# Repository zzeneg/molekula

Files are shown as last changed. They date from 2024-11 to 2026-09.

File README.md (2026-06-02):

# molekula: keyboard & framework

## modular framework

This project aims to provide components for building modular ergo keyboards by separating one main PCB into central and side parts. **Side** is a dumb PCB, with key matrix only (up to 25 keys), and accepts all switch types (MX/ChocV1/ChocV2/GLP). **Central** is a keyboard brain, which contains any MCU (wired/wireless/integrated) and additional hardware - encoders/touchpads/trackballs/displays/etc, while keeping its size under 100x100mm. PCBs are interconnected with 12-pin FFC cables, and can be replaced/updated independently.

Such modular approach allows for quick, cheap and easy experimenting with different hardware, prototyping, and reusing of side PCBs.

### PCB examples

- central with pro-micro/nice!nano footprint, nice!view and rotary encoder

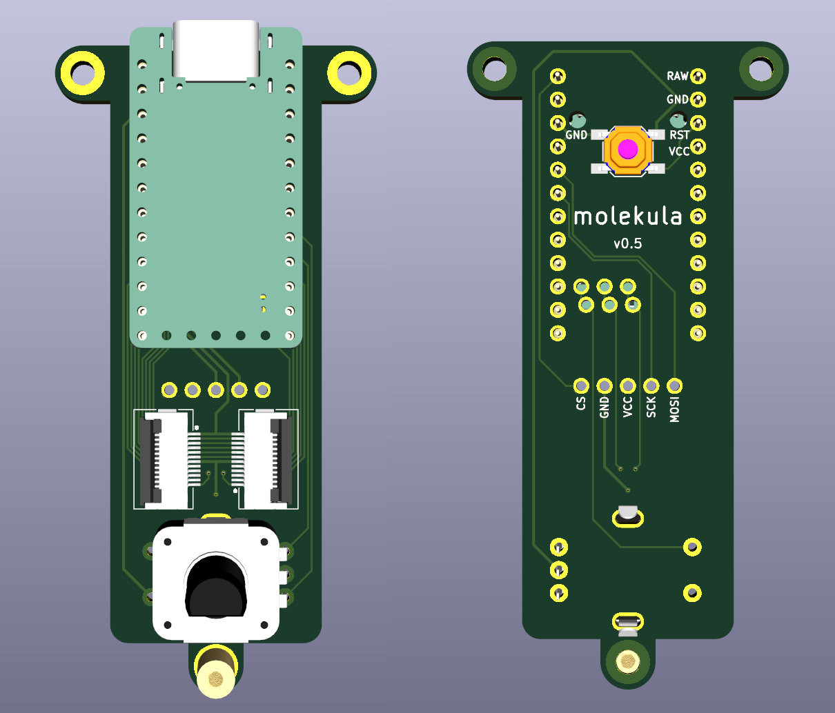
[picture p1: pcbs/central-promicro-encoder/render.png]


- side with 18 keys and minY spacing (19x16mm)

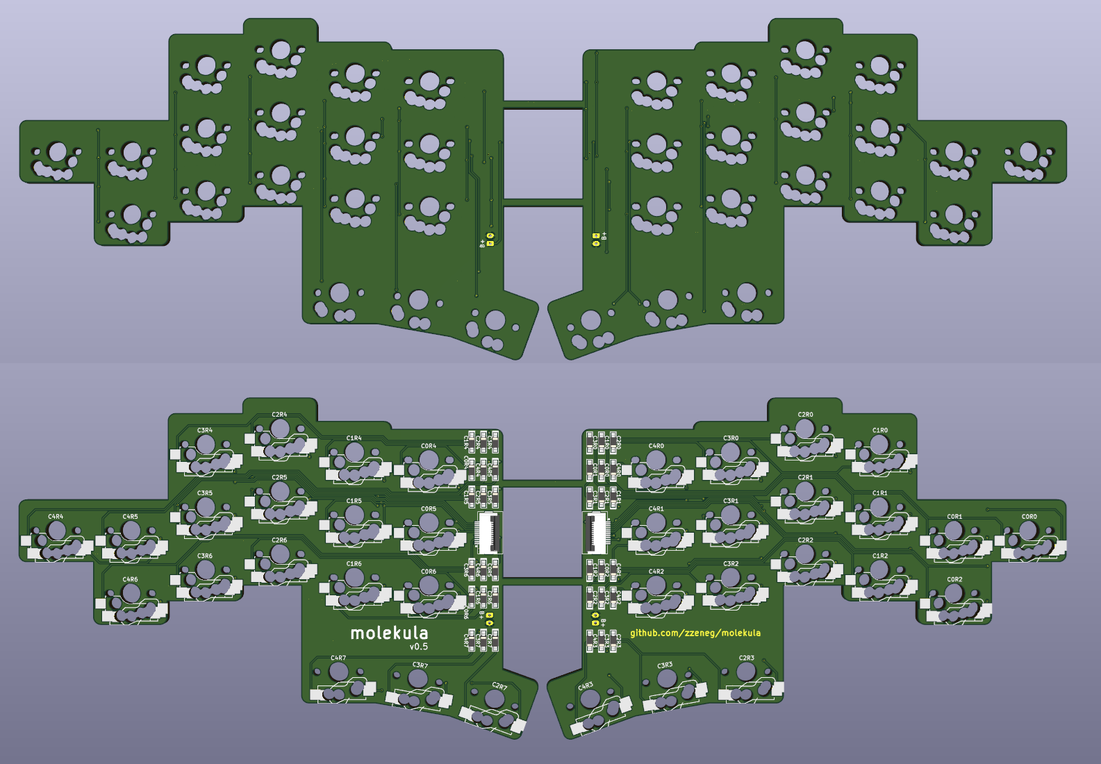
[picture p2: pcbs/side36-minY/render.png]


## Molekula keyboards

Reference design using molekula PCBs.

Features:

- minY (19x16mm) spacing
- 36 keys
- wireless
- nice!view support
- rotary encoder

### Molekula2

Unibody that can be disassembled into two parts for traveling

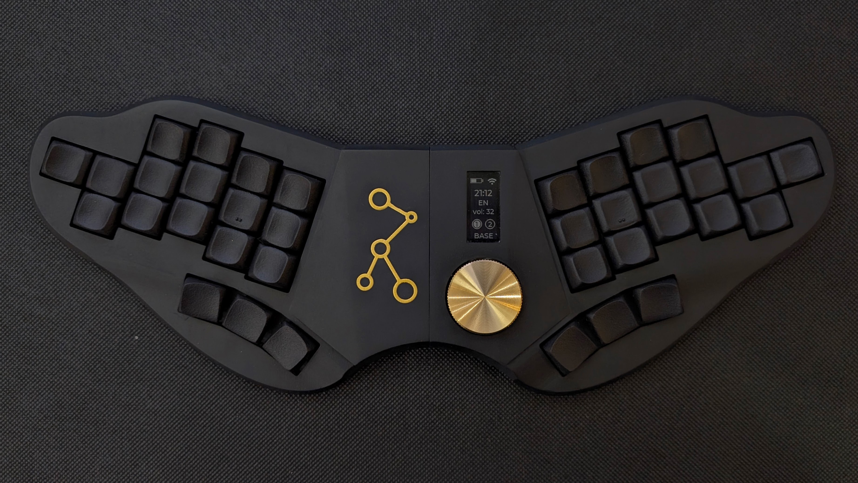
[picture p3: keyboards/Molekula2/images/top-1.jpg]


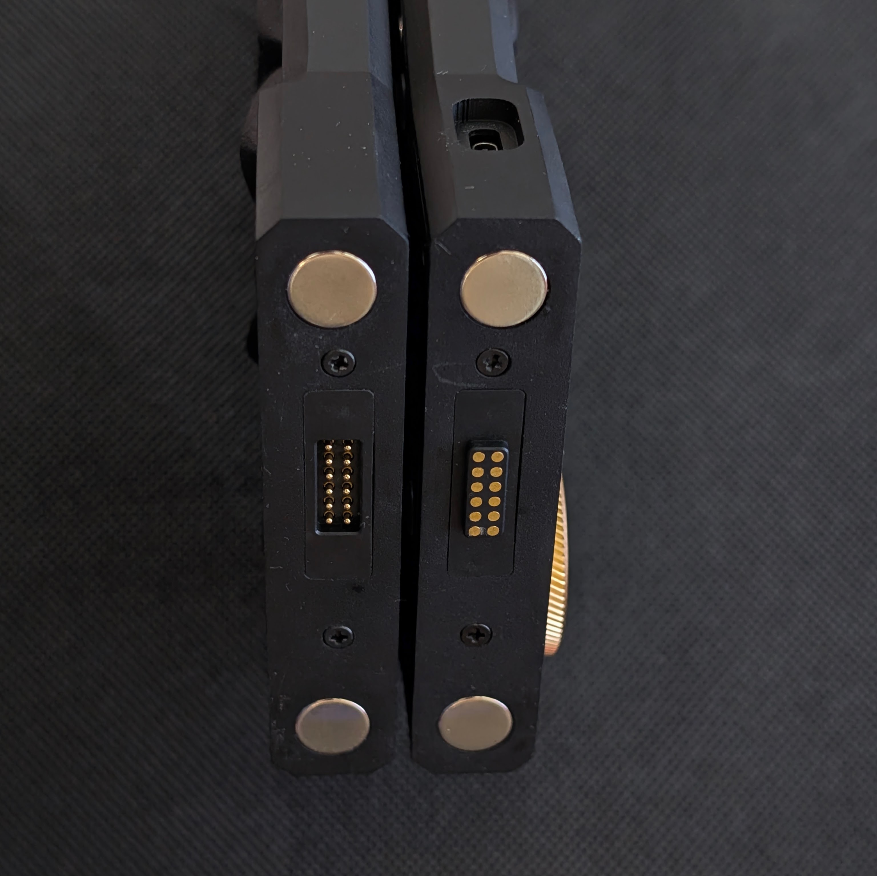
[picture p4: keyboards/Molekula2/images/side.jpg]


[More info and build guide](./keyboards/Molekula2/README.md)

### Molekula3

Unibody assembled from multiple parts, to allow easy modifications and experiments.

- optimised for FDM printing
- configurable angle and distance between sides (default is 18deg and 60mm)
- different options with dongle or nice!view
- MX/KS-33/ChocV1/ChocV2 are supported, except thumbs are low-profile only

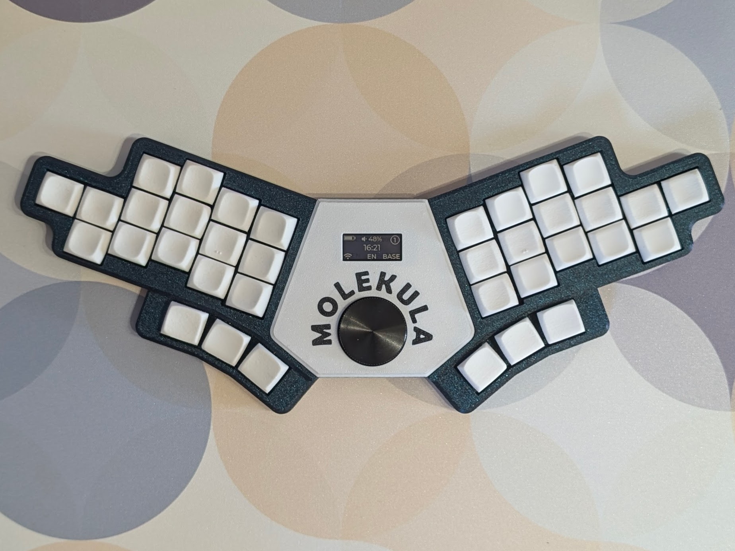
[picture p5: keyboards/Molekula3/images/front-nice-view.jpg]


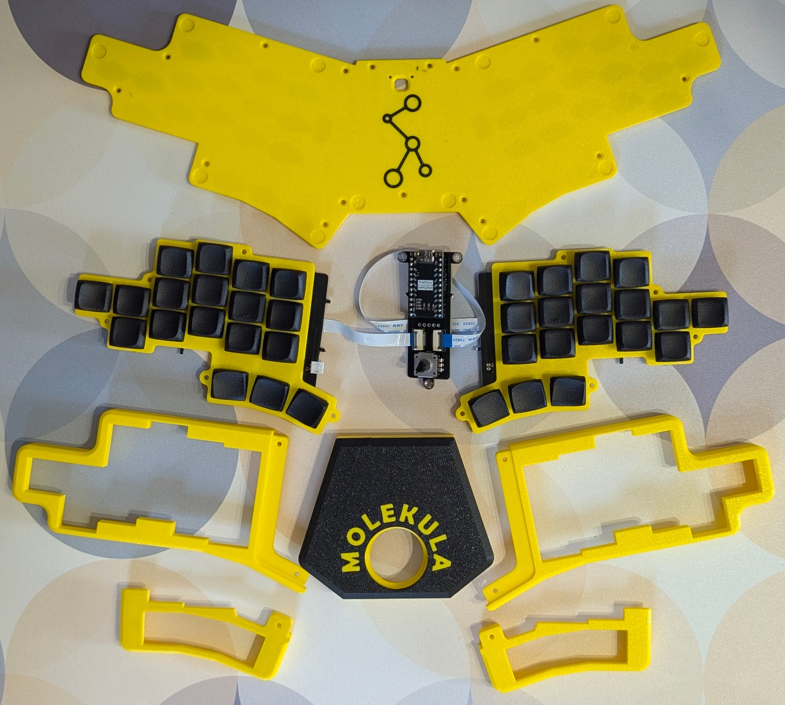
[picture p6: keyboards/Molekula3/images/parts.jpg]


[More info and build guide](./keyboards/Molekula3/README.md)

### minY keycaps

Keycaps designed for minY spacing (19mmx16mm):

- [MX DES](./keycaps/MX-DES-minY/)
- [Choc DES](./keycaps/MX-DES-minY/) - optimised for FDM printing

### Support

If you like my work and want to support my future designs, please consider [sponsorship](https://github.com/sponsors/zzeneg).

### Sponsors

Molekula2 keyboard was sponsored by PCBWay. I can highly recommend their PCBA and 3D printing services - "Imaging Black" resin looks fantastic.





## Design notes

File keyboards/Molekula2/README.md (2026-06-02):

## Molekula2 keyboard

Reference design using molekula framework PCBs.

Features:

- minY (19x16mm) spacing
- unibody that can be disassembled into two parts for traveling
- 36 keys
- wireless
- nice!view support
- rotary encoder



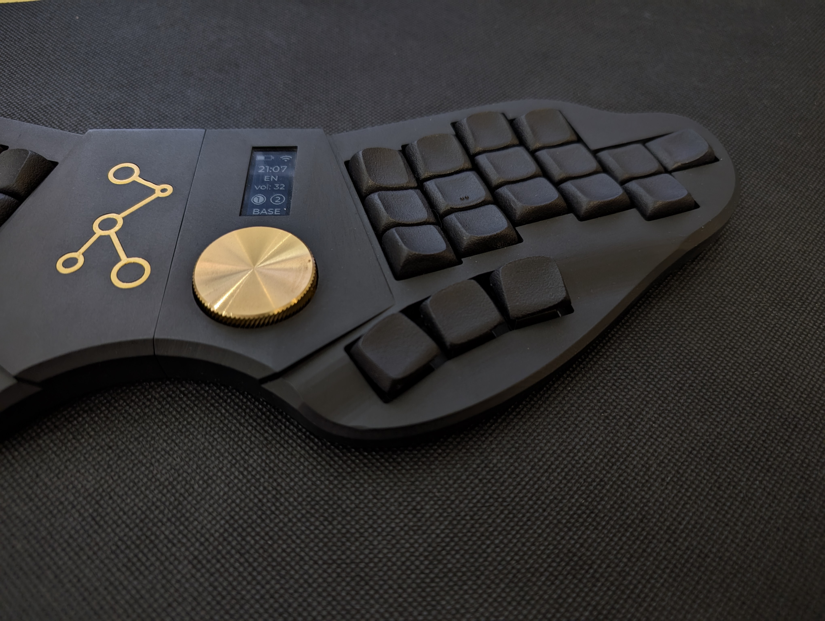
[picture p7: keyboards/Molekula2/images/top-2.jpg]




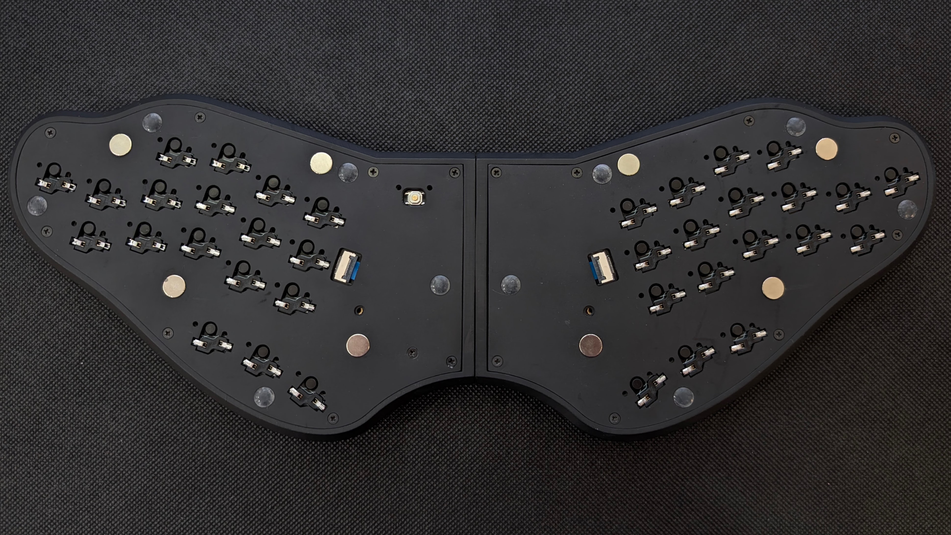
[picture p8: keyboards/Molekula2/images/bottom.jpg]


## Firmware

- [molekula shield](https://github.com/zzeneg/zmk-molekula) with default keymap and ZMK Studio support
- [my custom keymap](https://github.com/zzeneg/zmk-config), can be used as reference if needed

## Bill of materials

- MCU - nice!nano _(recommended to support original creator)_ or its chinese clone
- 36 MX/KS-33/Choc switches
- 36 MX/KS-33/Choc hotswap sockets
- 36 [SMD SOD-123 1N4148](https://www.aliexpress.com/item/1005002882901030.html) diodes
- Battery up to 602040 size - this is what I'm using, should be enough but you may try to go bigger (check that there's enough space inside using 3D project)
- _[Optional]_ Vertical 2pin 2.54mm JST [connector](https://www.aliexpress.com/item/1005004938361514.html) for battery
- [Magnetic connector 12pin](https://www.aliexpress.com/item/1005004609718442.html)
- 1 rotary encoder, [low profile EC12](https://www.aliexpress.com/item/1005003636548797.html) is recommended (no click though). Versions with click often has issues with power consumption, be careful
- 1 [30mm knob](https://www.aliexpress.com/item/1005001783212821.html)
- 4/5mm, 6/8mm and 10mm [M2 screws with flat head](https://www.aliexpress.com/item/4001248931159.html) (choose black or silver based on case color/preference)
- [M2 nuts](https://www.aliexpress.com/item/1005001412230125.html)
- M2 3/4mm [heatset inserts](https://www.aliexpress.com/item/1005004624377733.html) - diameter 3.2mm for resin case or 3.5mm for thermoplastic
- Vertical 12pin 0.5mm [FFC/FPC connector](https://www.aliexpress.com/item/10000000737049.html)
- Horizontal 12pin 0.5mm [FFC/FPC connector](https://www.aliexpress.com/item/10000348360254.html)
- 12pin 0.5mm 5cm [FFC cable](https://www.aliexpress.com/item/1005007561337665.html) - both reverse and same side variants
- SMD 4x4x1.5mm [push button](https://www.aliexpress.com/item/32802382507.html)
- [7x1.5mm legs](https://www.aliexpress.com/item/1005002995402961.html)
- [10x3mm magnets](https://www.aliexpress.com/item/1005006802780901.html) - for connecting sides
- [8x2mm magnets](https://www.aliexpress.com/item/1005005426580014.html) - for transportation (optional)
- 2.54mm female pin [headers](https://www.aliexpress.com/item/4001122376295.html)
- 5pin [headers](https://www.aliexpress.com/item/1005005742644313.html) - source of pins for socketing, and also a connector for nice!view

## PCBA

PCBA is recommended, all PCBs are combined into one, BOM and Position files are tested. If you can manually solder FFC connectors with 0.5mm pitch (it's totally doable), ignore PCBA and order PCBs separately.

## Case

See STLs in [./case]() folder. There are separate top/bottom parts for ChocV1/ChocV2/KS-33/MX switches. Also there is left side with and without logo. Separate logo can be printed in another color and inserted.

## Build guide

### Tools

- Soldering iron. Any iron will work, but I highly recommend something small like TS100 or Pinecil with TS-K tip, it's good for SMD soldering
- Solder wire, preferably with lead if you can get one. For EU I recommend this [shop](https://botland.store) and Cynel brand, 0.56mm and 0.9mm
- [Flux](https://www.aliexpress.com/item/1005004675178847.html)
- Flush cutters - be extra careful when cutting pins, always use eye protection
- Hot glue (for nice!view only), instant glue (for resin case only)
- Tweezers (I prefer [reverse](https://www.aliexpress.com/item/1005004188266714.html) instead of regular), pliers, soldering mat, isopropyl alcohol (IPA) and [cotton pads](https://www.aliexpress.com/item/1005003798227116.html) for cleaning

### Preparations

- download [latest firmware](https://github.com/zzeneg/zmk-molekula/actions), flash it to MCU and pair with your PC. It's easier to do it now and also check that MCU actually works
- read through the whole build guide
- break combined PCB into separate parts with pliers, do not sand break-offs

### Soldering

I used PCBA for final version, so I'll skip over FFC/diode soldering. Check my [duet guide](https://github.com/zzeneg/duet/blob/main/guide/readme.md) if needed.

#### Central

Start with MCU socketing (top side is the one with FFC connectors). Prepare MCU headers - you'll need two strips of 12 pins. Don't try to break the header between the pins, instead count the required number of pins, and break in middle of a next pin. Discard that pin and cut the plastic with flush cutters - it'll look much better. Assemble headers like this (using extra headers for stabilization):

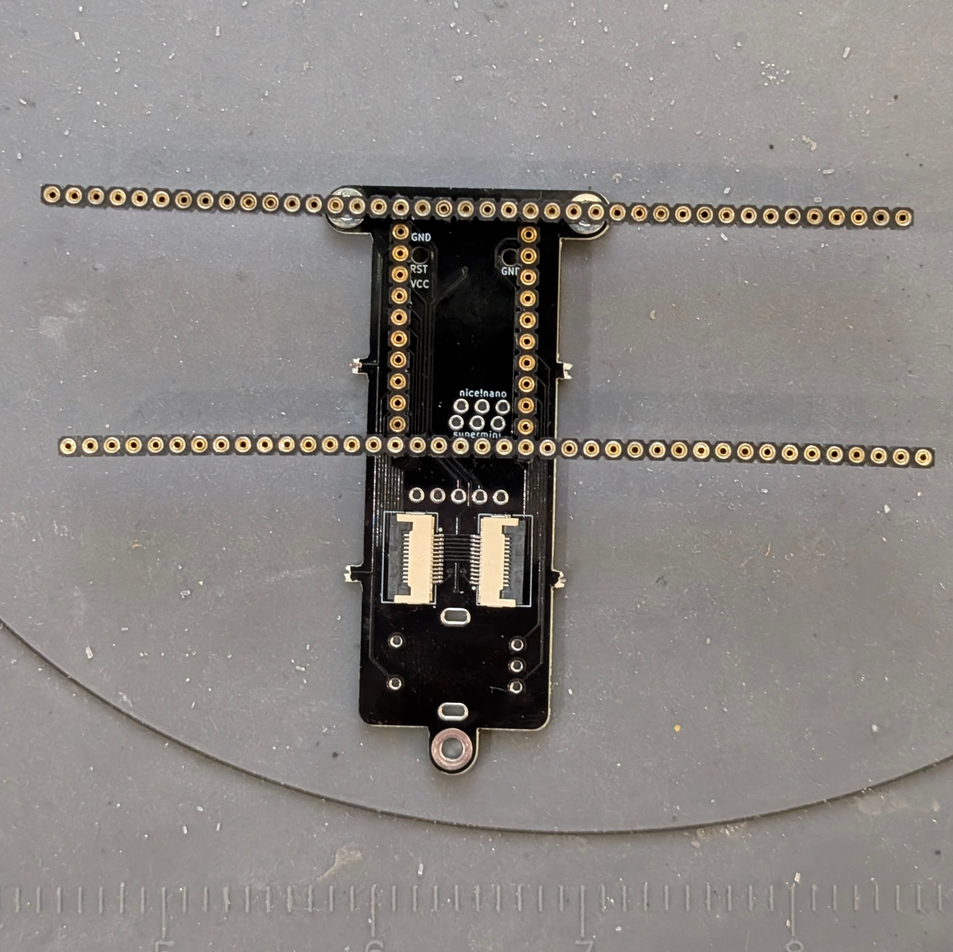
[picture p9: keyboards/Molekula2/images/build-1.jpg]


Flip carefully and solder all pins starting from corners. I prefer to cut first and then solder but you can cut afterwards as well, just remember to do it as bottom case has only 1.2mm space there. Pins in the middle are used only for encoder click, ignore them if you don't use it.

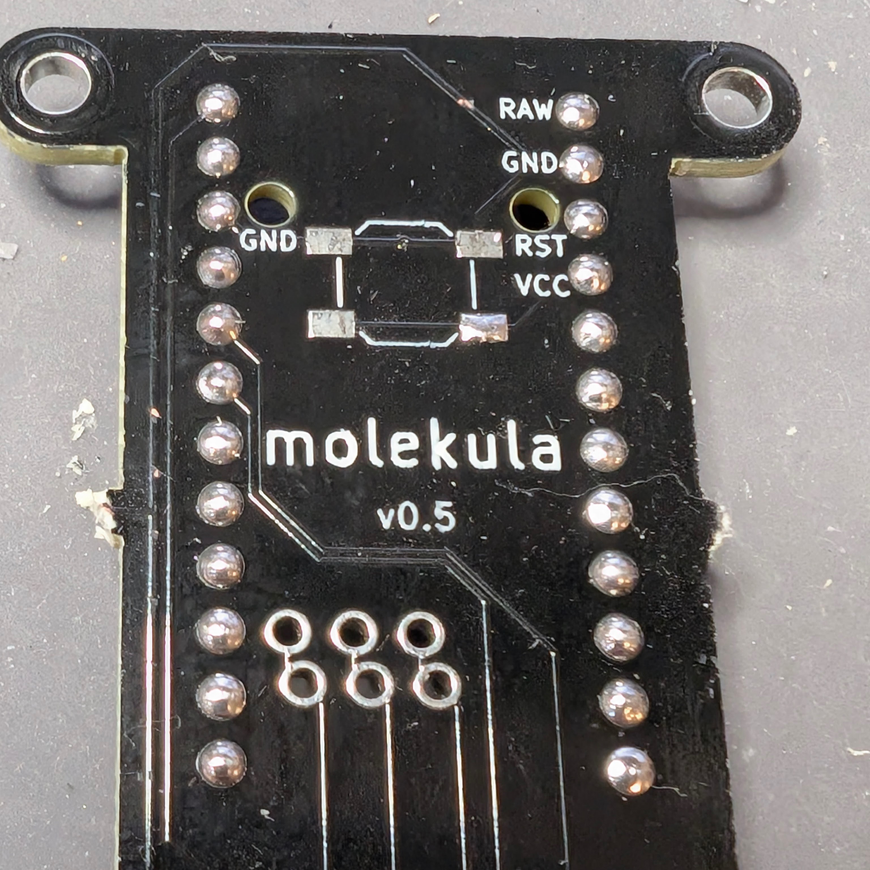
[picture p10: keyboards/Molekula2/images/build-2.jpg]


Pull out 24 pins from RGB headers (I use two pliers for that) and put a piece of masking tape over all headers leaving some space in between for MCU components.

Align MCU holes with headers ignoring top row of holes on the MCU, they are not used/soldered. Insert pins one by one (cut them if you prefer but it's not required). Solder everything starting from corners.

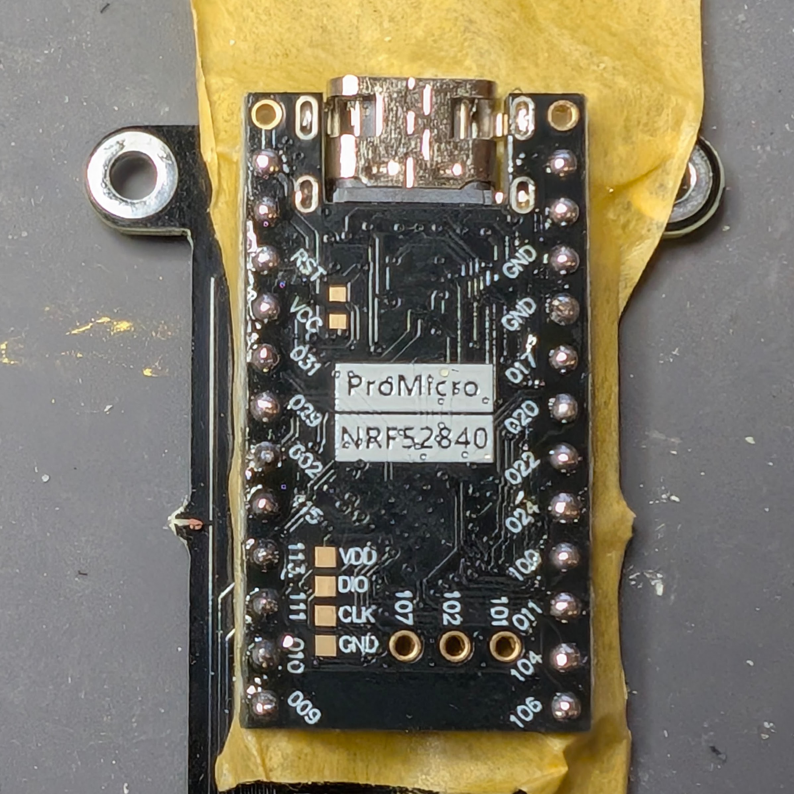
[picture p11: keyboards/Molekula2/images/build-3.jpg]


Carefully pull out socketed MCU and remove tape. Now solder the nice!view header and reset button on the back. Finish central with rotary encoder. Done.

#### Magnetic connectors

Prepare two connector PCB with soldered FFC connectors (if soldering manually, make sure black part is facing the side where the breakoffs are). Put them onto magnetic connectors, the one with a "leg" should be on the left side, and FFC's black part should be facing you.

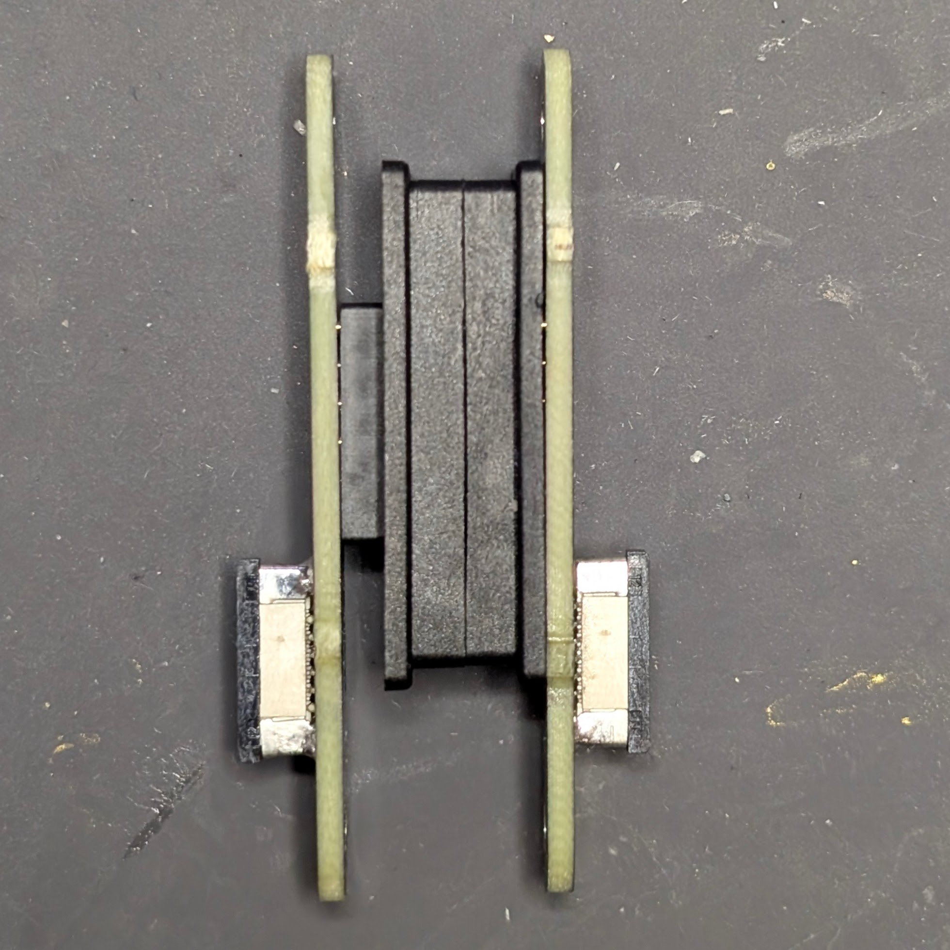
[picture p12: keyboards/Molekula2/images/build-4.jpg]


Take them apart and solder without flipping anything. It's a bit tricky because of magnets but doable with two hands. The easiest approach is to add a lot of flux and drag solder across all contacts.

#### Side PCBs

Just solder the hotswap sockets. They are not symmetrical, look at silkscreen on how to place them. Make sure that socket is fully inserted into the PCB. You have use a lot of solder as there are a lot of holes but try to avoid big solder blobs - they may collide with bottom case.

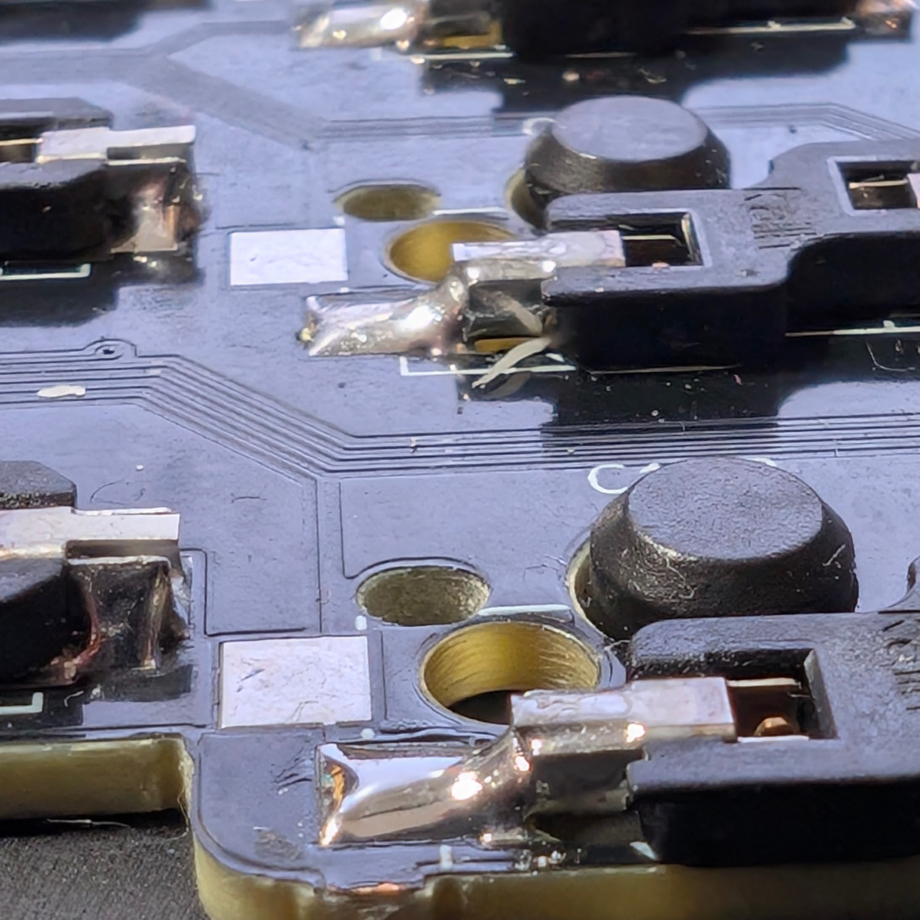
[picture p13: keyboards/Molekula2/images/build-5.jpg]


If you want a JST socket for the battery - solder it to the left PCB (JST should be on the top side). Double check the polarity on the battery connector, and do not connect it yet.

#### nice!view

Take a 5-pin header and carefully move pins, leaving around 1.5mm on one side and solder short side to nice!view.

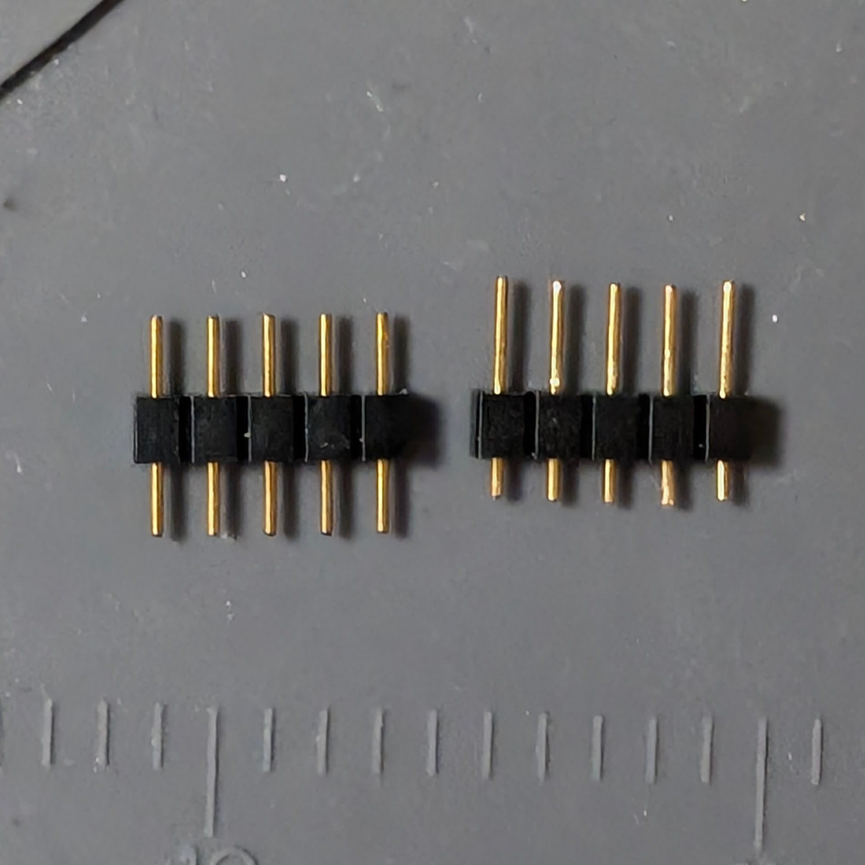
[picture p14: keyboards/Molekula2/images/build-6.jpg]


Attach nice!view to the case with hot glue - add more around the pins.

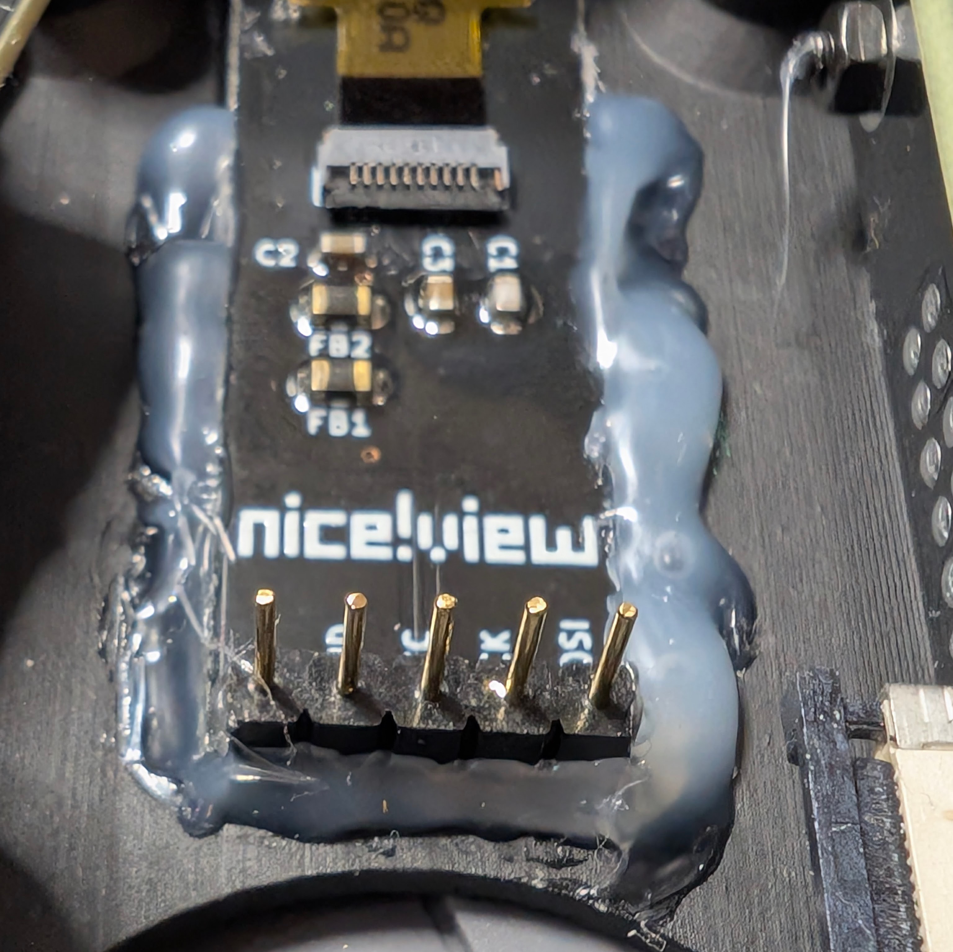
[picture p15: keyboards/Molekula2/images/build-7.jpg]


#### Assembly

First insert socketed MCU and attach all FFC cables outside the case and perform basic checks for shorts between BAT/GND/VCC/B+/B-. If everything is ok, solder your battery to the PCB or connect it with JST.

Put screw inserts into the case. For thermoplastics (MJF, PLA, etc) use 3.5mm-wide and look at [this guide](https://docs.bastardkb.com/bg_charybdis/04screw_inserts.html) for detailed instructions on heat inserts. For resin case take 3.2mm inserts and use instant glue (cyanoacrylate) and/or a drill if the holes are too narrow.

Insert 10mm magnets, they should go all the way in so there is no gap between sides, use more force if needed. If loose, add a bit of instant glue inside.

Assemble left side first - insert magnetic connector into the case (bigger one with a "leg") with already attached FFC cable, fix connector PCB in place with 10mm screws. Hot glue your battery to the case, and connect FFC to side PCB. Insert several switches to hold the PCB in place.

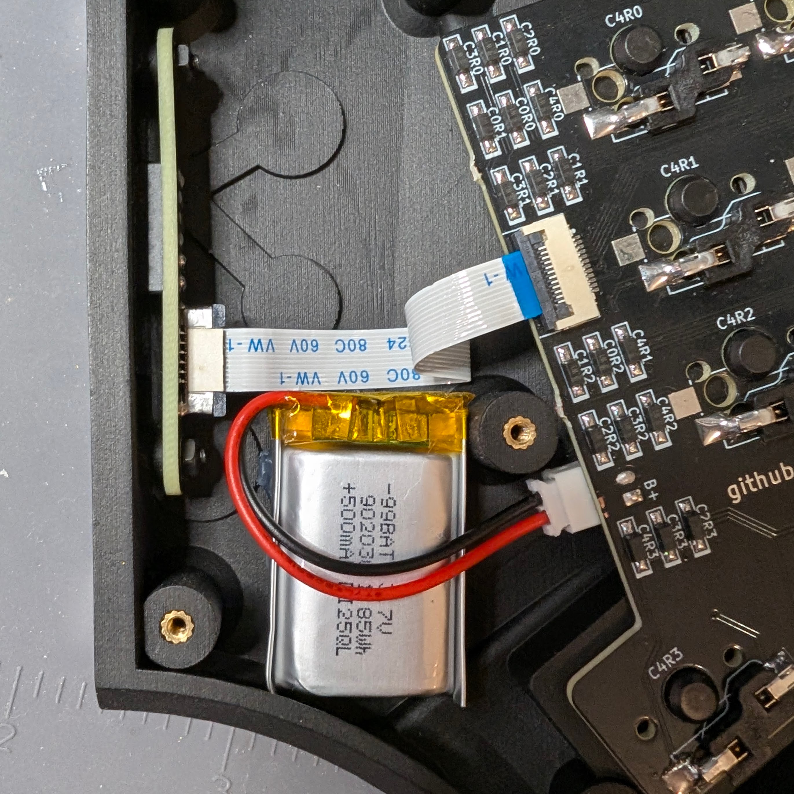
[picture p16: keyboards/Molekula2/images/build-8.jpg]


Now right side - start with magnetic connector, for this side use 6-8mm screws. Connect FFC cables, carefully put central PCB in place, looking at n!v pins. After that, bend and press the FFC cable going to magnetic connector - it should be flat to hide under encoder knob (the other cable has a lot of place).

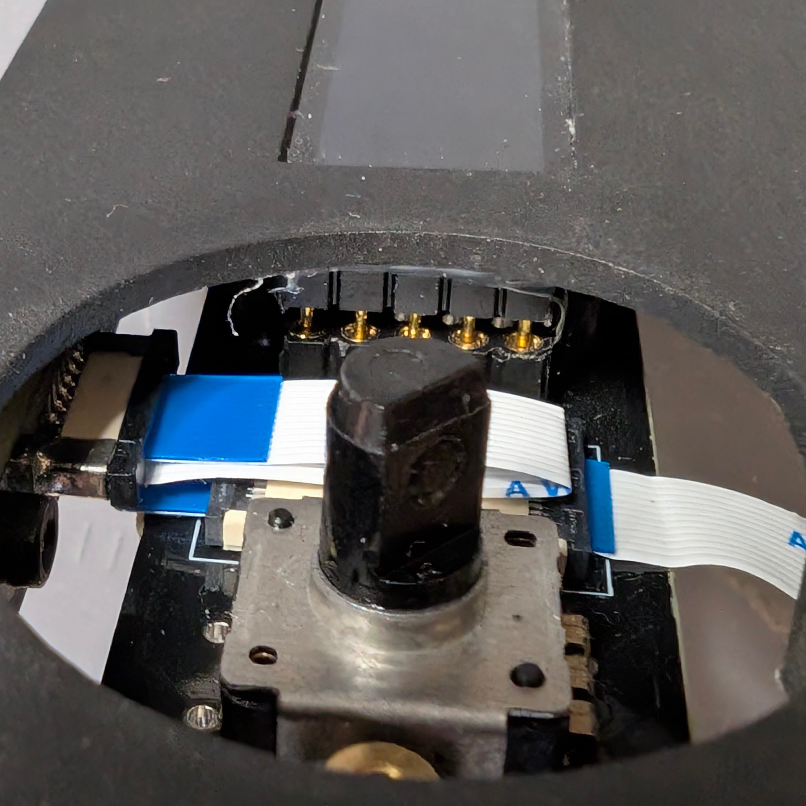
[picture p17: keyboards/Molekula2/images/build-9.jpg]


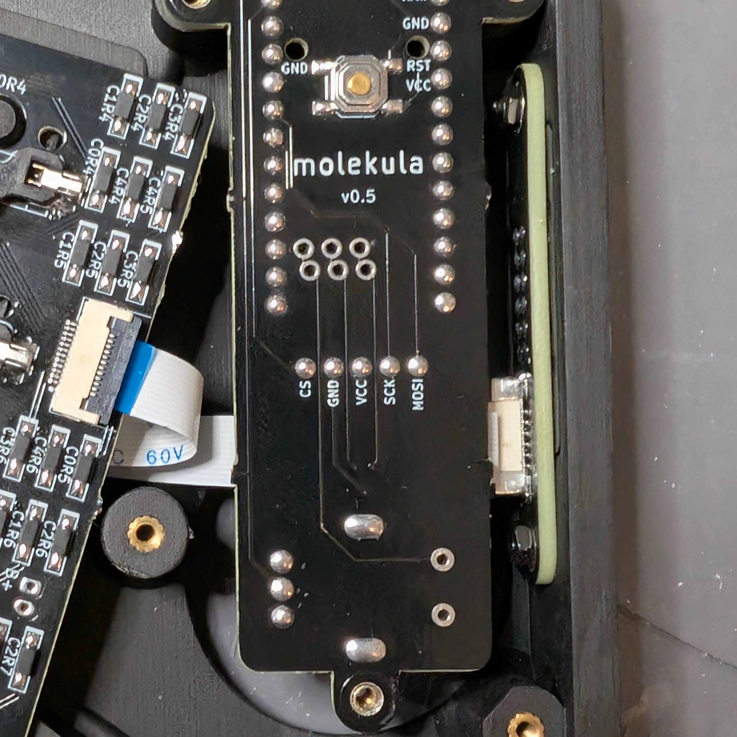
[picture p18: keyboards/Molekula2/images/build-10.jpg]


Now attach encoder knob. I recommend to put it around 2-3mm higher than the lowest position.

Last step is to add bottom plate, use 4-5mm screws for this.

Done!

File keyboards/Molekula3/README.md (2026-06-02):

## Molekula3 keyboard

Unibody assembled from multiple parts, to allow easy modifications and experiments.

- optimised for FDM printing
- configurable angle and distance between sides
- different options with and without nice!view





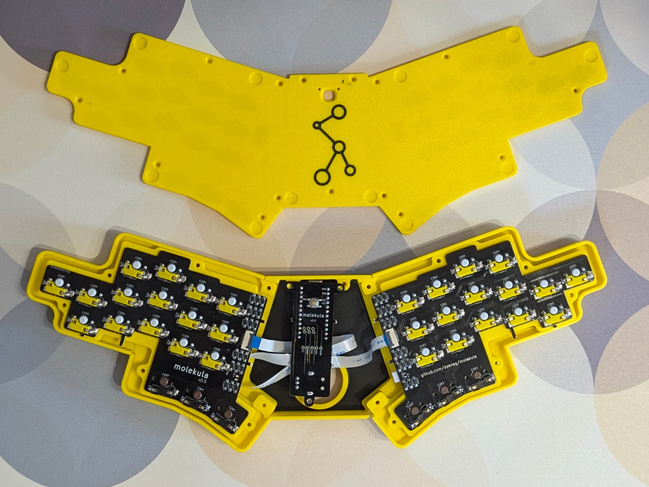
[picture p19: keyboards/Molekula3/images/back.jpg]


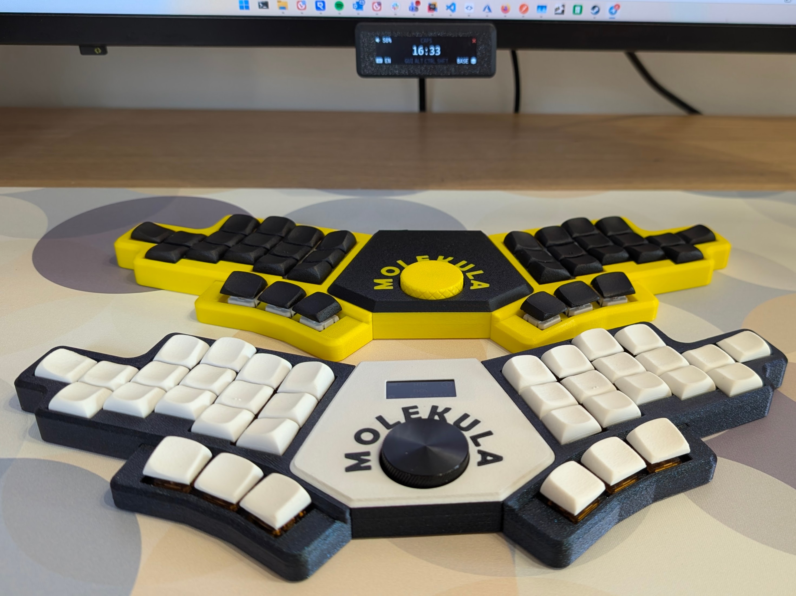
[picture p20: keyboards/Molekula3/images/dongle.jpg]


## Firmware

- [molekula shield](https://github.com/zzeneg/zmk-molekula) with default keymap and ZMK Studio support, with variants for horizontal nice!view and [dongle](https://github.com/zzeneg/underdongle)
- [my custom keymap](https://github.com/zzeneg/zmk-config), can be used as reference if needed

## Bill of materials

- MCU - nice!nano _(recommended to support original creator)_ or its chinese clone
- 36 (30 MX/KS-33/Choc + 6 KS-33/Choc) switches
- 36 (30 MX/KS-33/Choc + 6 KS-33/Choc) hotswap sockets
- 36 [SMD SOD-123 1N4148](https://www.aliexpress.com/item/1005002882901030.html) diodes
- Battery like 902030 size - this is what I'm using, should be enough but you may try to go bigger (check that there's enough space inside using 3D project)
- _[Optional]_ Vertical 2pin 2.54mm JST [connector](https://www.aliexpress.com/item/1005004938361514.html) for battery
- 1 rotary encoder, [low profile EC12](https://www.aliexpress.com/item/1005003636548797.html) is recommended (no click though). Versions with click often has issues with power consumption, be careful
- 1 [30mm knob](https://www.aliexpress.com/item/1005001783212821.html) - or 3D printed one
- 8mm and 14mm [M2 screws with flat head](https://www.aliexpress.com/item/4001248931159.html) (choose black or silver based on case color/preference)
- [M2 nuts](https://www.aliexpress.com/item/1005001412230125.html)
- M2 2mm and 4mm [heatset inserts](https://www.aliexpress.com/item/1005004624377733.html) - diameter 3.2mm for resin case or 3.5mm for thermoplastic
- Horizontal 12pin 0.5mm [FFC/FPC connector](https://www.aliexpress.com/item/10000348360254.html)
- 12pin 0.5mm 5cm [FFC cable](https://www.aliexpress.com/item/1005007561337665.html) - reverse variant
- SMD 4x4x1.5mm [push button](https://www.aliexpress.com/item/32802382507.html)
- [7x1.5mm feet](https://www.aliexpress.com/item/1005002619943801.html)
- 2.54mm female pin [headers](https://www.aliexpress.com/item/4001122376295.html)
- 5pin [headers](https://www.aliexpress.com/item/1005005742644313.html) - source of pins for socketing, and also a connector for nice!view

## PCBA

PCBA is recommended, all PCBs are combined into one, BOM and Position files are tested. If you can manually solder FFC connectors with 0.5mm pitch (it's totally doable), ignore PCBA and order PCBs separately.

## Case

See STLs in [./case]() folder. Files are grouped into folders based on MX/LowProfile and exact switches. Feel free to modify the Fusion 360 files for custom dimensions.

Printing should be easy, supports are required only for the left/right sides.

If you don't want/like logos, just combine STLs into one.

## Build guide

See [build guide for molekula2](./../Molekula2/README.md), just ignore everything about connectors and magnets.

Use 2mm heatset insert for central and thumb parts, and 4mm for sides.

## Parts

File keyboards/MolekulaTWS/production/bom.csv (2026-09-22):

Designator | Footprint | Quantity | Value | LCSC Part #
D1, D10, D11, D12, D13, D14, D15, D16, D17, D18, D19, D2, D20, D21, D22, D23, D24, D25, D26, D27, D28, D29, D3, D30, D31, D32, D33, D34, D35, D36, D4, D5, D6, D7, D8, D9 | Diode_1N4148-SOD123 | 36 | C81598
H1, H2, H3 | Hole_M2-solder-nut-2.5 | 3 | MountingHole
J12, J5_2, J7 | Connector_JST-1x02-2.00mm | 3 | Conn_01x02_Socket
J2, J4, J5 | Connector_FFC-12pin-0.5mm-horizontal | 3 | C479750
J3 | PinHeader_1x02_P2.54mm_Vertical | 1 | Conn_01x02_Pin
SW1, SW10, SW11, SW12, SW13, SW14, SW15, SW16, SW17, SW18, SW19, SW2, SW20, SW21, SW22, SW23, SW24, SW25, SW26, SW27, SW28, SW29, SW3, SW30, SW31, SW32, SW33, SW34, SW35, SW36, SW4, SW5, SW6, SW7, SW8, SW9 | Switch_MXKSChoc-hotswap-choc-spacing | 36 | Switch
SW34_2 | Switch_SPDT-PCM12 | 1 | SW_SPDT
SW37 | Button_SW_SPST_SKQG_WithoutStem | 1 | SW_Push
SW38 | RotaryEncoder_EC11 | 1 | RotaryEncoder_Switch
U1 | MCU_xiao-ble-tht | 1 | MCU_xiao-ble

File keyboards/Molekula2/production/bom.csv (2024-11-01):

Designator | Footprint | Quantity | Value | LCSC Part #
D1, D10, D11, D12, D13, D14, D15, D16, D17, D18, D19, D2, D20, D21, D22, D23, D24, D25, D26, D27, D28, D29, D3, D30, D31, D32, D33, D34, D35, D36, D4, D5, D6, D7, D8, D9 | Diode_1N4148-SOD123 | 36 | C81598
J2, J3, J4, J5 | Connector_FFC-12pin-0.5mm-horizontal | 4 | C479750
J8, J9 | Connector_FFC-12pin-0.5mm-vertical | 2 | C262499

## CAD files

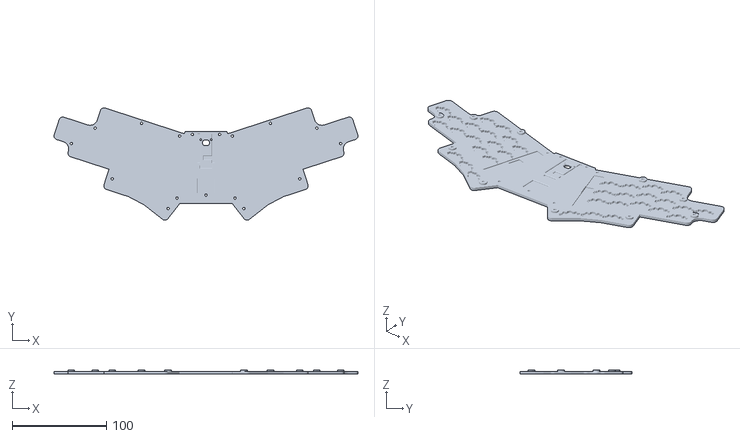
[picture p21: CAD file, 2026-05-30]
keyboards/Molekula3/case/common/bottom-full.stl
323.1 x 119.4 x 4.40

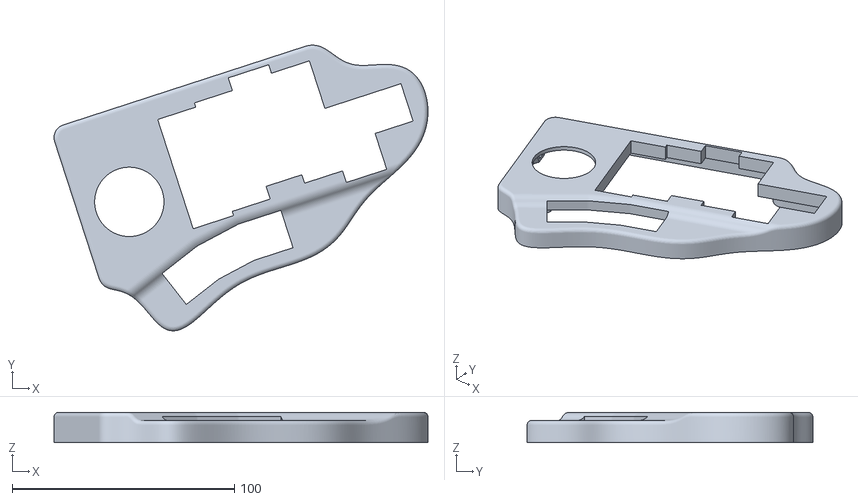
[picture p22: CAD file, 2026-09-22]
keyboards/MolekulaTWS/case/choc-spacing/tws-full-curved-right.stl
168.3 x 128.6 x 13.6

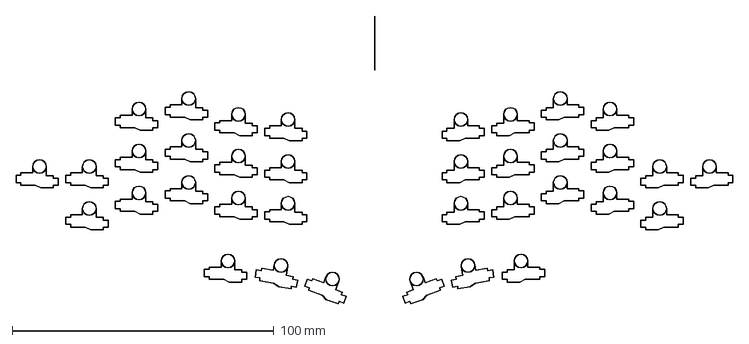
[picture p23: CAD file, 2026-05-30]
keyboards/Molekula2/case/bottom-left-ks cutout.dxf
274.0 x 109.9 mm

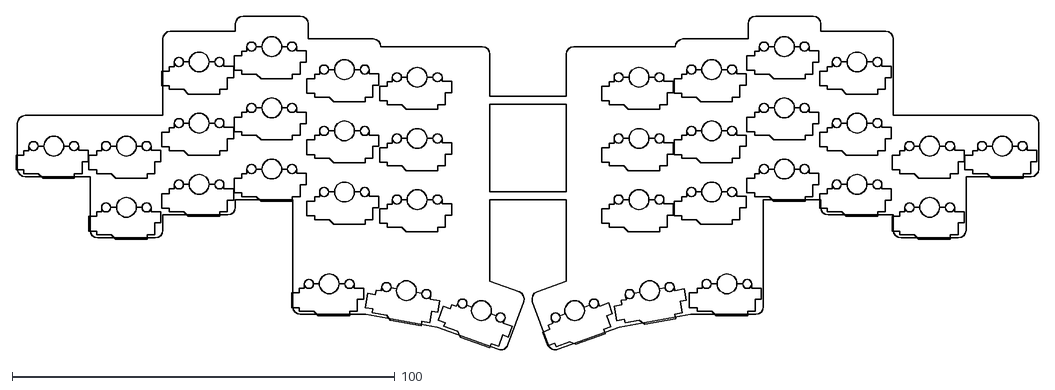
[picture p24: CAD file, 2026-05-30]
keyboards/Molekula3/case/bottom-cutout.dxf
267.3 x 87.3

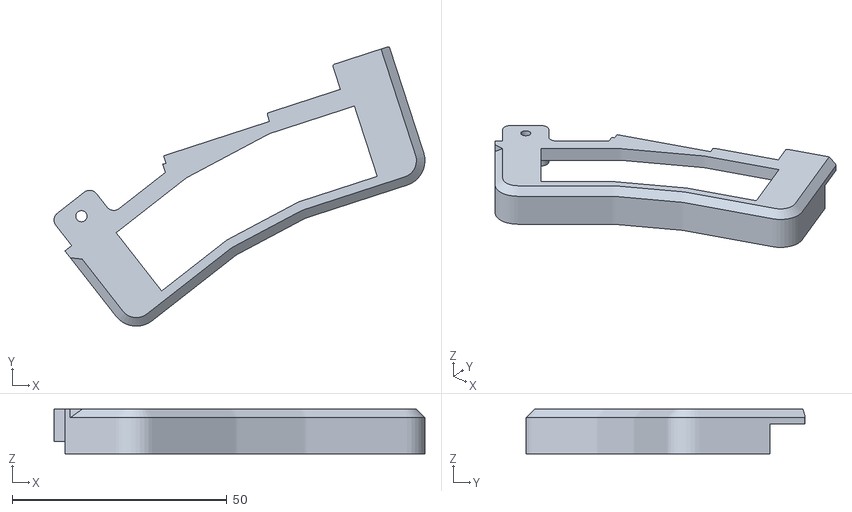
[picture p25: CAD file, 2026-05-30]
keyboards/Molekula3/case/common/thumb-right.stl
86.3 x 65.0 x 10.4

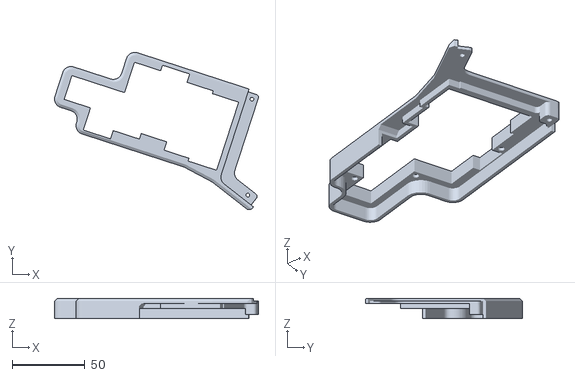
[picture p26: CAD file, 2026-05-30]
keyboards/Molekula3/case/LP/top-left.stl
140.1 x 108.1 x 14.0

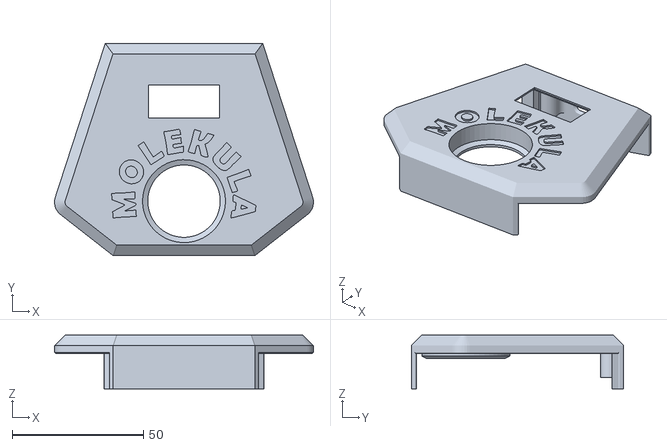
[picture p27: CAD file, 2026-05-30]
keyboards/Molekula3/case/MX/center-nice-view.stl
98.7 x 80.9 x 20.5

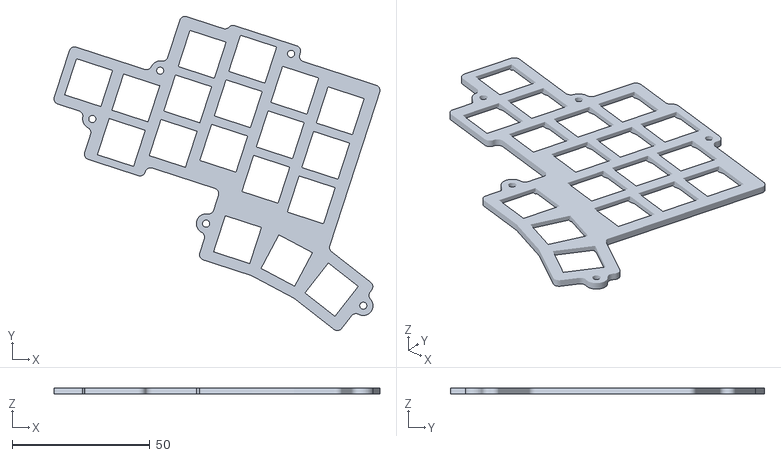
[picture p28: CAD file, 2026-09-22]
keyboards/MolekulaTWS/case/choc-spacing/ChocV1/plate-left.stl
118.3 x 114.0 x 2.20

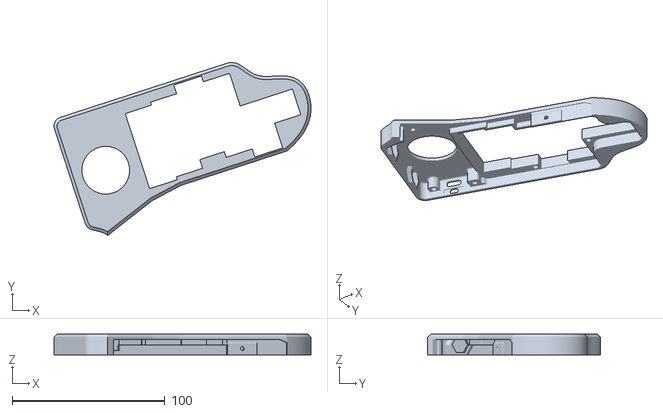
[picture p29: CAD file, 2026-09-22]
keyboards/MolekulaTWS/case/choc-spacing/tws-top-curved-right.stl
168.3 x 113.3 x 13.6

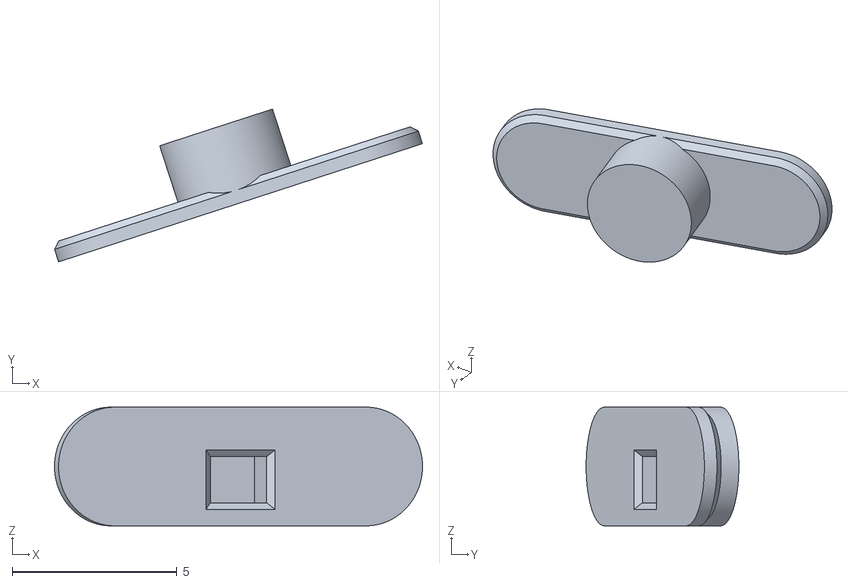
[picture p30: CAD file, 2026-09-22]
keyboards/MolekulaTWS/case/common/tws-power-switch.stl
11.2 x 4.63 x 3.60

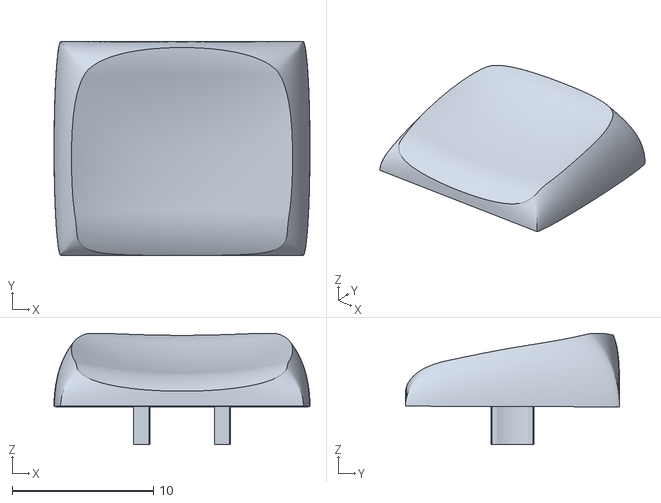
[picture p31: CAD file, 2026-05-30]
keycaps/Choc-DES-minY-FDM/Choc_DES_minY-thumb-mid.stl
18.1 x 15.1 x 7.88

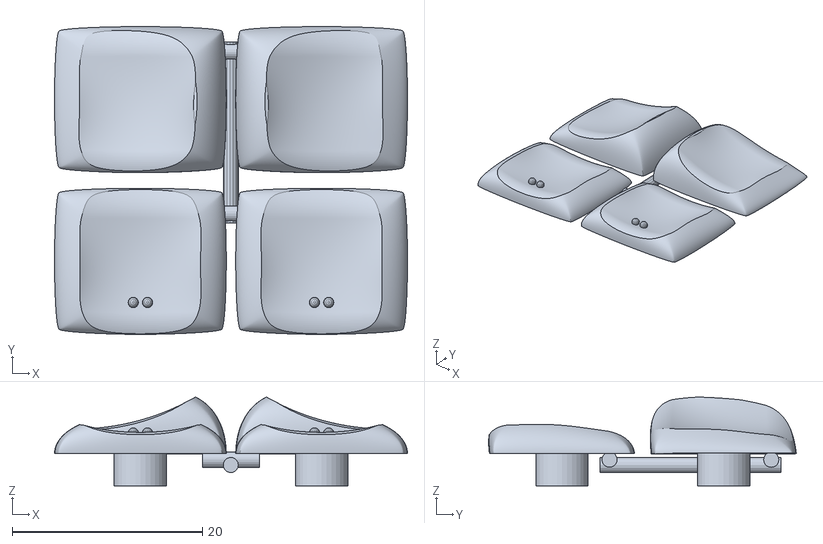
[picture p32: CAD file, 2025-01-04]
keycaps/MX-DES-minY/DES_r3_dot_x2_r3_edge_x2.stl
37.1 x 32.4 x 9.34

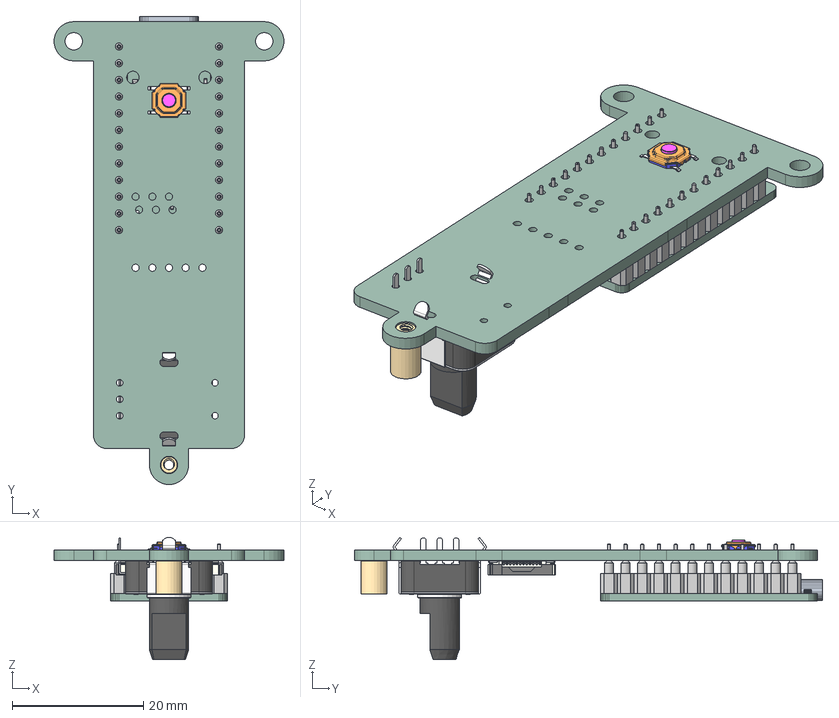
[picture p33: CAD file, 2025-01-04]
pcbs/central-promicro-encoder/mcu.step
35.0 x 71.3 x 18.6 mm
splinky-headers v2
Button_SW_SPST_SKQG_WithoutStem v1
FPC-12 x 2
solder-nut v2
EC12_10mm (3)
mcu_PCB

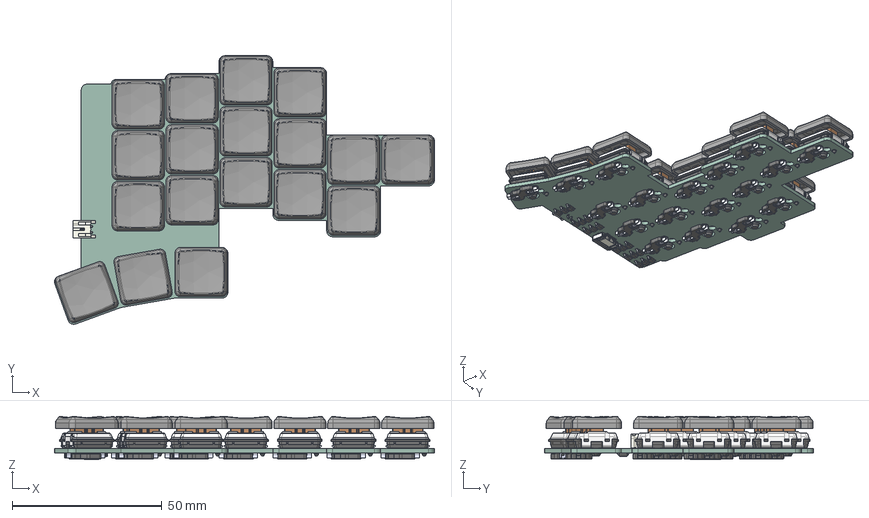
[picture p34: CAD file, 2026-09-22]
pcbs/side36-choc/pcb-right-choc-spacing.step
126.9 x 89.7 x 14.4 mm
pin x 36
socket x 18
(Unsaved) x 18
Document x 90
JST_S2B_PH_K
D_SOD-123 v1 x 18
FPC-12
side36-choc_PCB

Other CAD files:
keyboards/MolekulaTWS/case/choc-spacing/tws-full-curved-left.stl
pcbs/side36-minY/side36-right-mx-chocV2.step
pcbs/tws-xiao-encoder/tws-xiao-encoder.step
keyboards/Molekula2/case/bottom-right-mx cutout.dxf
keyboards/Molekula2/case/bottom-left-choc-cutout.dxf
keyboards/Molekula2/case/bottom-left-choc.stl
keyboards/Molekula2/case/bottom-left-ks.stl
keyboards/Molekula2/case/bottom-left-mx cutout.dxf
keyboards/Molekula2/case/bottom-left-mx.stl
keyboards/Molekula2/case/bottom-right-choc-cutout.dxf
keyboards/Molekula2/case/bottom-right-choc.stl
keyboards/Molekula2/case/bottom-right-ks cutout.dxf
keyboards/Molekula2/case/bottom-right-ks.stl
keyboards/Molekula2/case/bottom-right-mx.stl
keyboards/Molekula2/case/ledview.stl
keyboards/Molekula2/case/logo.stl
keyboards/Molekula2/case/top-left-logo_chocV1.stl
keyboards/Molekula2/case/top-left-logo_chocV2.stl
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

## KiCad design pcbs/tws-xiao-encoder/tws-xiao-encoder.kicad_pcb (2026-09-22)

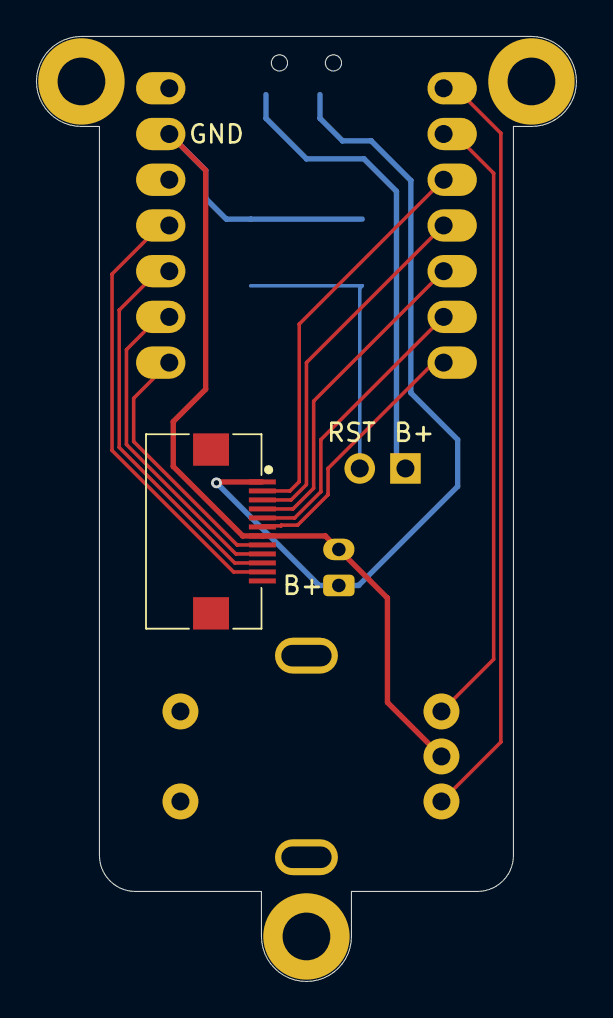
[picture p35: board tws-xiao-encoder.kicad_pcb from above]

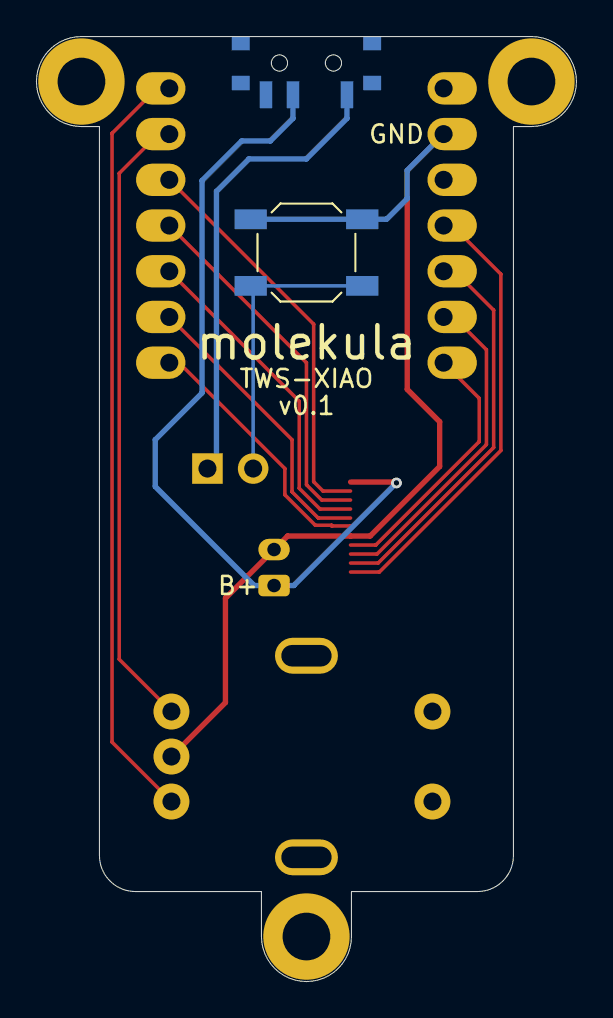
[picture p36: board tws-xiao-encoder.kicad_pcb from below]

Board: 2 copper layers, 30.0 x 52.5 mm, 10 parts (3 on the bottom side), 15 nets.

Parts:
H1, H2, H3: MountingHole; Hole_M2-solder-nut-2.5
J2: C479750; Connector_FFC-12pin-0.5mm-horizontal
J3: Conn_01x02_Pin; PinHeader_1x02_P2.54mm_Vertical
J5: Conn_01x02_Socket; Connector_JST-1x02-2.00mm
SW34: SW_SPDT; Switch_SPDT-PCM12
SW37: SW_Push; Button_SW_SPST_SKQG_WithoutStem
SW38: RotaryEncoder_Switch; RotaryEncoder_EC11
U1: MCU_xiao-ble; MCU_xiao-ble-tht

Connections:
BAT: J2.1, J5.1, SW34.2 (B)
BAT-mcu: J3.1, SW34.1 (A)
GND: J2.7, J5.2, SW37.1, SW38.C, U1.13 (GND)
GPIO1: SW38.A, U1.1 (A2/0.02_H)
GPIO2: SW38.B, U1.2 (A4/0.03_H)
RST: J3.2, SW37.2
col0-mcu: J2.6, U1.7 (B8_TX/1.11)
col1-mcu: J2.5, U1.6 (A9_SCL/0.05_H)
col2-mcu: J2.4, U1.5 (A8_SDA/0.04_H)
col3-mcu: J2.3, U1.4 (A11/0.29)
col4-mcu: J2.2, U1.3 (A10/0.28)
row0-mcu: J2.11, U1.11 (A6_MOSI/1.15)
row1-mcu: J2.10, U1.10 (A5_MISO/1.14)
row2-mcu: J2.9, U1.9 (A7_SCK/1.13)
row3-mcu: J2.8, U1.8 (B9_RX/1.12)

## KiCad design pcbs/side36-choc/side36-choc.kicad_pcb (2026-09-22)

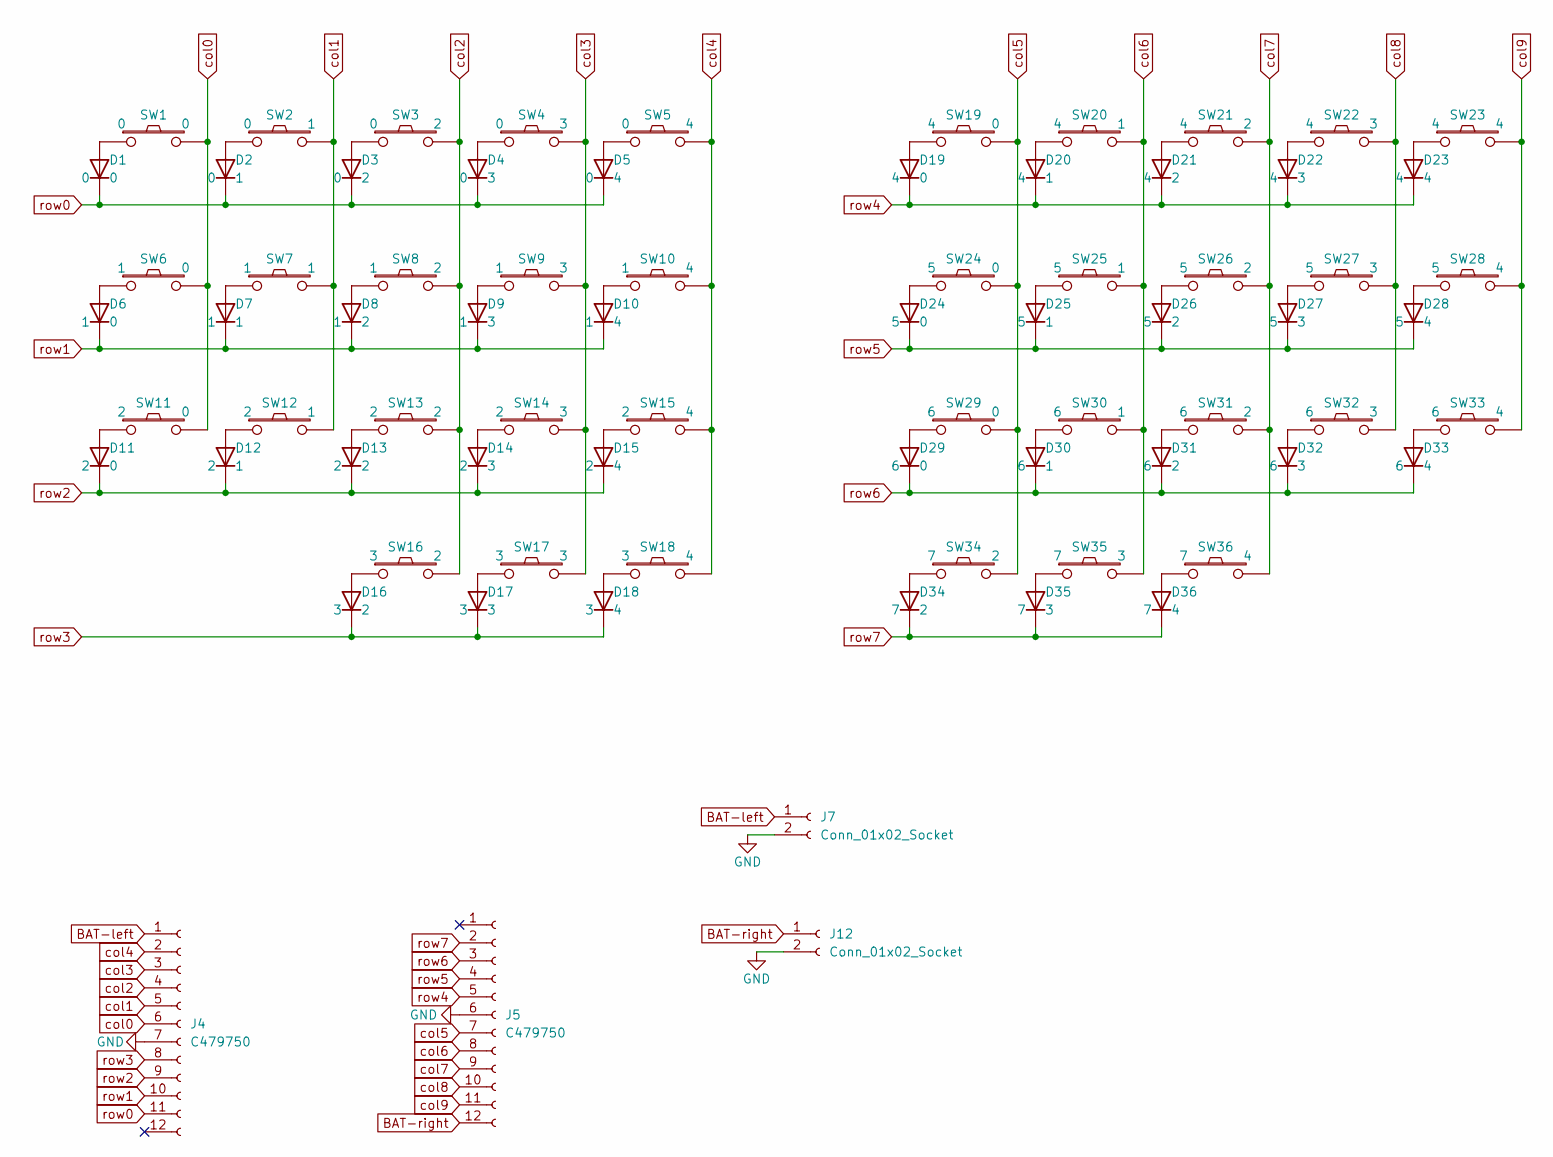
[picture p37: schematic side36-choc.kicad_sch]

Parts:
D1, D2, D3, D4, D5, D6, D7, D8, D9, D10, D11, D12, D13, D14, D15, D16, D17, D18, D19, D20, D21, D22, D23, D24, D25, D26, D27, D28, D29, D30, D31, D32, D33, D34, D35, D36: C81598; Diode_1N4148-SOD123
J4, J5: C479750; Connector_FFC-12pin-0.5mm-horizontal
J7, J12: Conn_01x02_Socket; Connector_JST-1x02-2.00mm
SW1, SW2, SW3, SW4, SW5, SW6, SW7, SW8, SW9, SW10, SW11, SW12, SW13, SW14, SW15, SW16, SW17, SW18, SW19, SW20, SW21, SW22, SW23, SW24, SW25, SW26, SW27, SW28, SW29, SW30, SW31, SW32, SW33, SW34, SW35, SW36: Switch; Switch_MXKSChoc-hotswap-choc-spacing

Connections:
BAT-left: J4.1, J7.1
BAT-right: J5.12, J12.1
GND: J4.7, J5.6, J7.2, J12.2
unnamed: D1.2 (A), SW1.1
unnamed: D2.2 (A), SW2.1
unnamed: D3.2 (A), SW3.1
unnamed: D4.2 (A), SW4.1
unnamed: D5.2 (A), SW5.1
unnamed: D6.2 (A), SW6.1
unnamed: D7.2 (A), SW7.1
unnamed: D8.2 (A), SW8.1
unnamed: D9.2 (A), SW9.1
unnamed: D10.2 (A), SW10.1
unnamed: D11.2 (A), SW11.1
unnamed: D12.2 (A), SW12.1
unnamed: D13.2 (A), SW13.1
unnamed: D14.2 (A), SW14.1
unnamed: D15.2 (A), SW15.1
unnamed: D16.2 (A), SW16.1
unnamed: D17.2 (A), SW17.1
unnamed: D18.2 (A), SW18.1
unnamed: D19.2 (A), SW19.1
unnamed: D20.2 (A), SW20.1
unnamed: D21.2 (A), SW21.1
unnamed: D22.2 (A), SW22.1
unnamed: D23.2 (A), SW23.1
unnamed: D24.2 (A), SW24.1
unnamed: D25.2 (A), SW25.1
unnamed: D26.2 (A), SW26.1
unnamed: D27.2 (A), SW27.1
unnamed: D28.2 (A), SW28.1
unnamed: D29.2 (A), SW29.1
unnamed: D30.2 (A), SW30.1
unnamed: D31.2 (A), SW31.1
unnamed: D32.2 (A), SW32.1
unnamed: D33.2 (A), SW33.1
unnamed: D34.2 (A), SW34.1
unnamed: D35.2 (A), SW35.1
unnamed: D36.2 (A), SW36.1
col0: J4.6, SW1.2, SW6.2, SW11.2
col1: J4.5, SW2.2, SW7.2, SW12.2
col2: J4.4, SW3.2, SW8.2, SW13.2, SW16.2
col3: J4.3, SW4.2, SW9.2, SW14.2, SW17.2
col4: J4.2, SW5.2, SW10.2, SW15.2, SW18.2
col5: J5.7, SW19.2, SW24.2, SW29.2, SW34.2
col6: J5.8, SW20.2, SW25.2, SW30.2, SW35.2
col7: J5.9, SW21.2, SW26.2, SW31.2, SW36.2
col8: J5.10, SW22.2, SW27.2, SW32.2
col9: J5.11, SW23.2, SW28.2, SW33.2
row0: D1.1 (K), D2.1 (K), D3.1 (K), D4.1 (K), D5.1 (K), J4.11
row1: D6.1 (K), D7.1 (K), D8.1 (K), D9.1 (K), D10.1 (K), J4.10
row2: D11.1 (K), D12.1 (K), D13.1 (K), D14.1 (K), D15.1 (K), J4.9
row3: D16.1 (K), D17.1 (K), D18.1 (K), J4.8
row4: D19.1 (K), D20.1 (K), D21.1 (K), D22.1 (K), D23.1 (K), J5.5
row5: D24.1 (K), D25.1 (K), D26.1 (K), D27.1 (K), D28.1 (K), J5.4
row6: D29.1 (K), D30.1 (K), D31.1 (K), D32.1 (K), D33.1 (K), J5.3
row7: D34.1 (K), D35.1 (K), D36.1 (K), J5.2

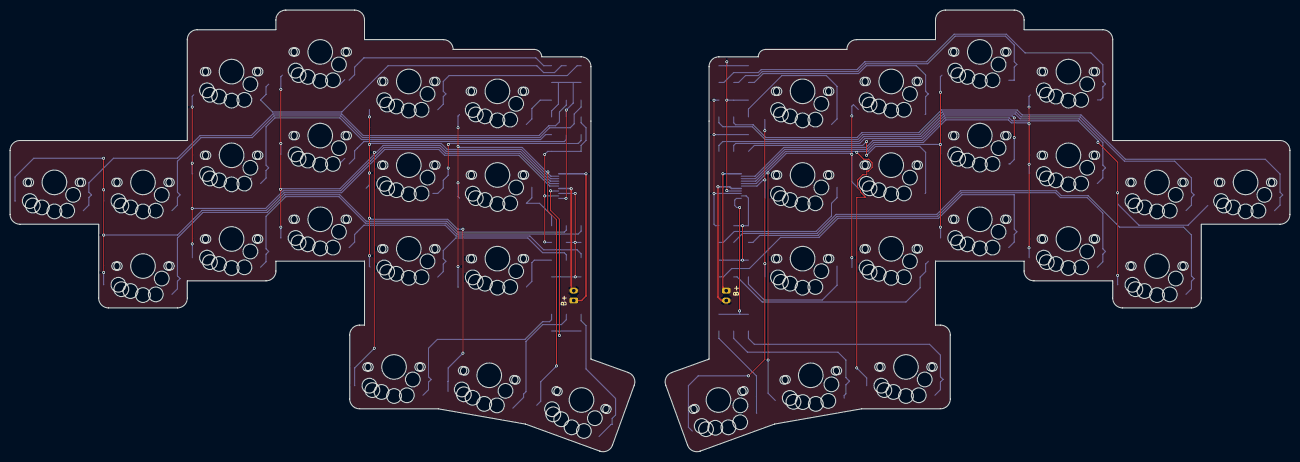
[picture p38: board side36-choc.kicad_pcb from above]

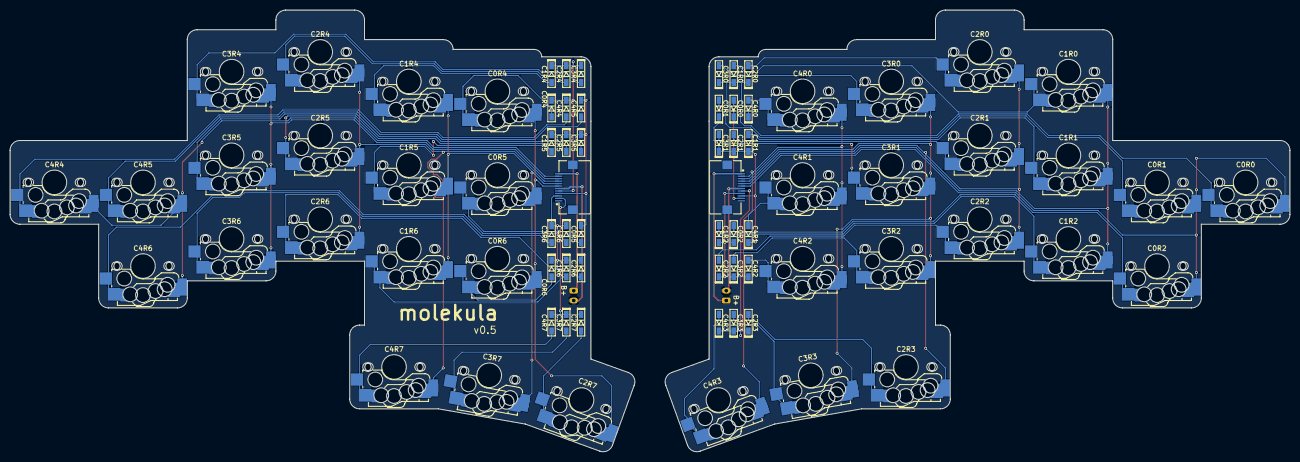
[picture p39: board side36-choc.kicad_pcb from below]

Board: 2 copper layers, 260.0 x 89.7 mm, 76 parts (38 on the bottom side), 57 nets.

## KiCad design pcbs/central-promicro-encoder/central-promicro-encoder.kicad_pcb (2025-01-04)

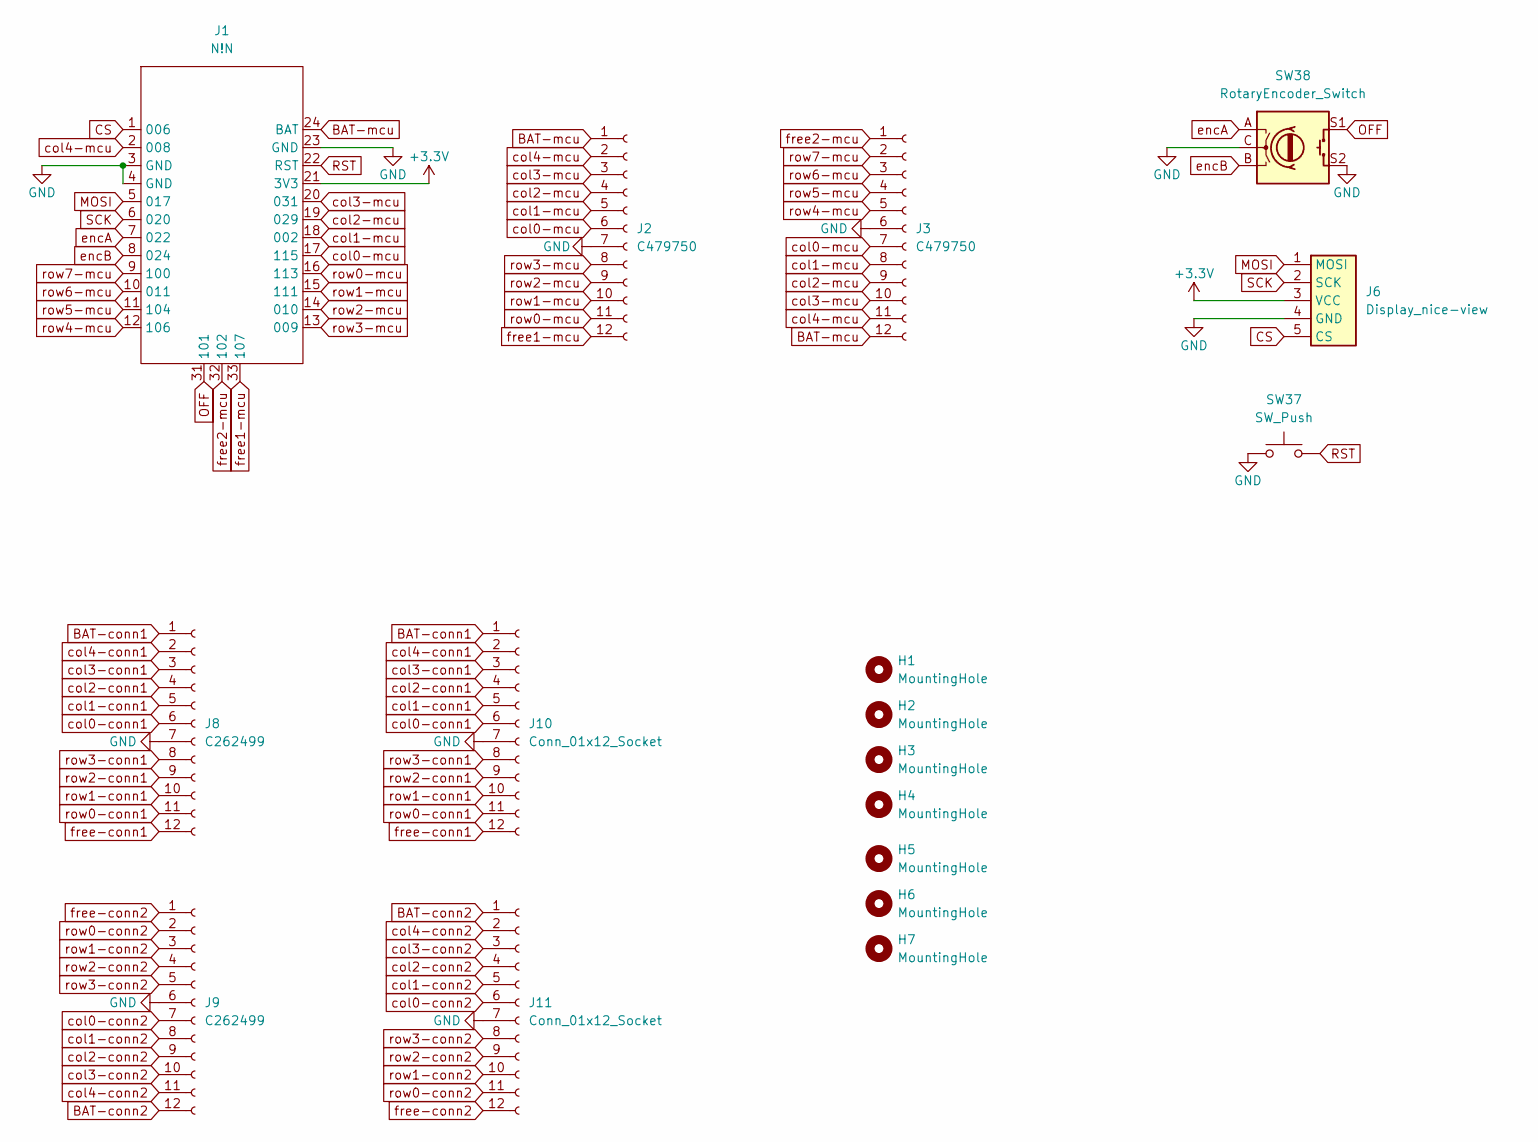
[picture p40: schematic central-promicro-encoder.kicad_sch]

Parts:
H1, H2, H3, H4, H5, H6, H7: MountingHole; Hole_M2-solder-nut-2.5
J1: N!N; MCU_nice-nano
J2, J3: C479750; Connector_FFC-12pin-0.5mm-horizontal
J6: Display_nice-view
J8, J9: C262499; Connector_FFC-12pin-0.5mm-vertical
J10, J11: Conn_01x12_Socket; Connector_Magnetic-12pin
SW37: SW_Push; Button_SW_SPST_SKQG_WithoutStem
SW38: RotaryEncoder_Switch; RotaryEncoder_EC11

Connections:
+3.3V: J1.21 (3V3), J6.3 (VCC)
BAT-conn1: J8.1, J10.1
BAT-conn2: J9.12, J11.1
BAT-mcu: J1.24 (BAT), J2.1, J3.12
CS: J1.1 (006), J6.5 (CS)
GND: J1.3 (GND), J1.4 (GND), J1.23 (GND), J2.7, J3.6, J6.4 (GND), J8.7, J9.6, J10.7, J11.7, SW37.1, SW38.C, SW38.S2
MOSI: J1.5 (017), J6.1 (MOSI)
OFF: J1.31 (101), SW38.S1
RST: J1.22 (RST), SW37.2
SCK: J1.6 (020), J6.2 (SCK)
col0-conn1: J8.6, J10.6
col0-conn2: J9.7, J11.6
col0-mcu: J1.17 (115), J2.6, J3.7
col1-conn1: J8.5, J10.5
col1-conn2: J9.8, J11.5
col1-mcu: J1.18 (002), J2.5, J3.8
col2-conn1: J8.4, J10.4
col2-conn2: J9.9, J11.4
col2-mcu: J1.19 (029), J2.4, J3.9
col3-conn1: J8.3, J10.3
col3-conn2: J9.10, J11.3
col3-mcu: J1.20 (031), J2.3, J3.10
col4-conn1: J8.2, J10.2
col4-conn2: J9.11, J11.2
col4-mcu: J1.2 (008), J2.2, J3.11
encA: J1.7 (022), SW38.A
encB: J1.8 (024), SW38.B
free1-mcu: J1.33 (107), J2.12
free2-mcu: J1.32 (102), J3.1
free-conn1: J8.12, J10.12
free-conn2: J9.1, J11.12
row0-conn1: J8.11, J10.11
row0-conn2: J9.2, J11.11
row0-mcu: J1.16 (113), J2.11
row1-conn1: J8.10, J10.10
row1-conn2: J9.3, J11.10
row1-mcu: J1.15 (111), J2.10
row2-conn1: J8.9, J10.9
row2-conn2: J9.4, J11.9
row2-mcu: J1.14 (010), J2.9
row3-conn1: J8.8, J10.8
row3-conn2: J9.5, J11.8
row3-mcu: J1.13 (009), J2.8
row4-mcu: J1.12 (106), J3.5
row5-mcu: J1.11 (104), J3.4
row6-mcu: J1.10 (011), J3.3
row7-mcu: J1.9 (100), J3.2

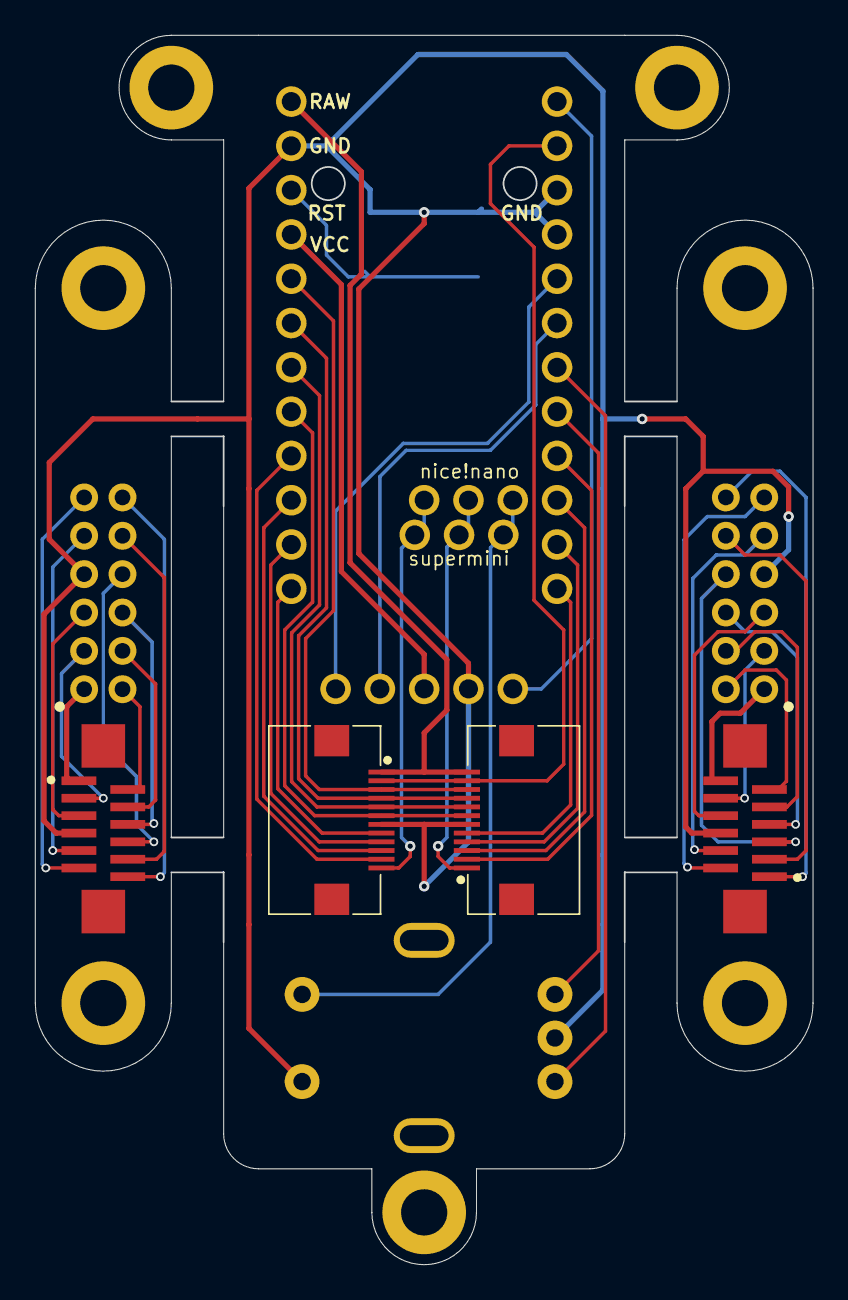
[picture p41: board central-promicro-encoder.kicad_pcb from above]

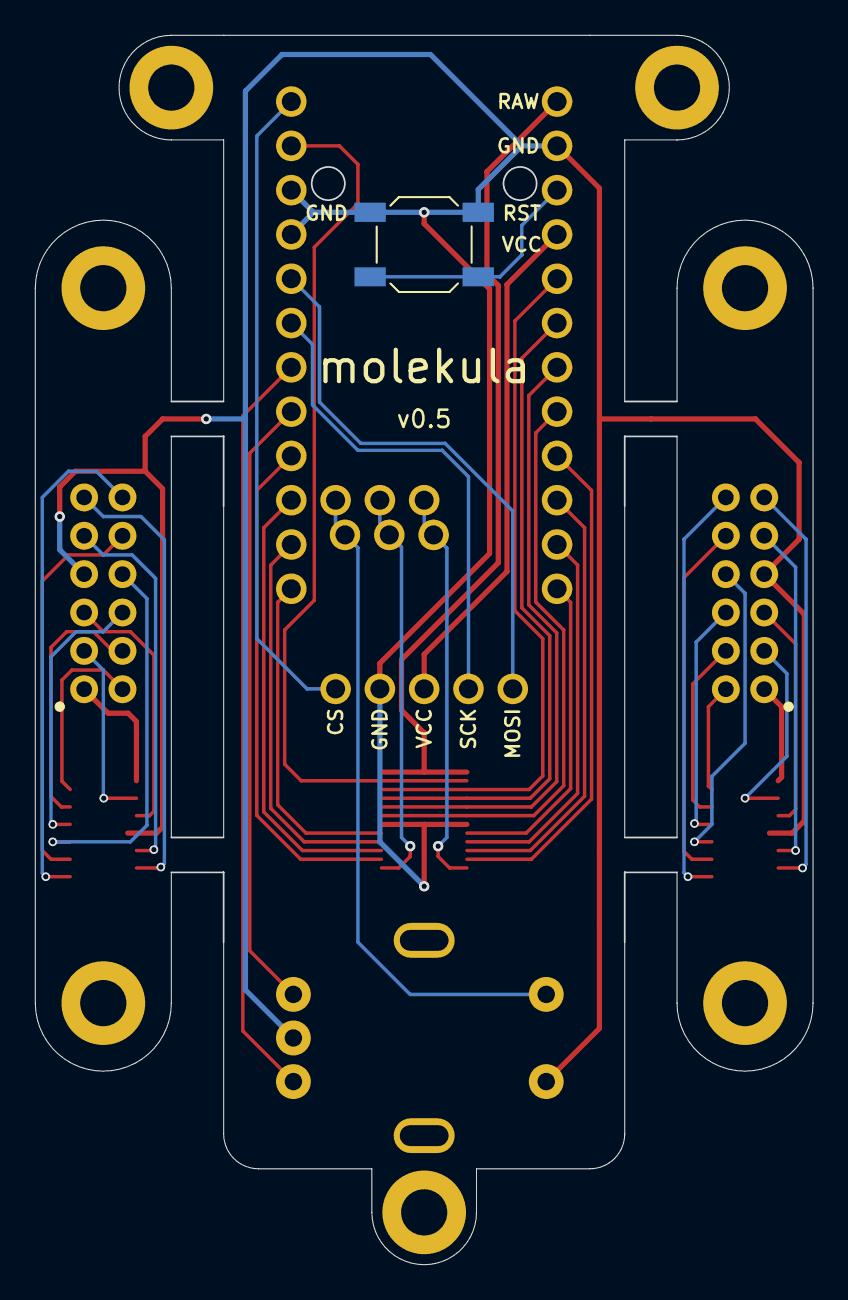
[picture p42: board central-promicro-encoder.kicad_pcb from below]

Board: 2 copper layers, 44.6 x 70.5 mm, 17 parts (3 on the bottom side), 47 nets.

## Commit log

2024-05-08 first draft
    [connector-left.kicad_pcb, connector-left.step, connector-right.kicad_pcb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]
2024-06-11 second draft
    [connector-left.kicad_pcb, connector-left.step, connector-right.kicad_pcb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]
2024-06-28 update pin names
    [pcb.kicad_pcb, pcb.kicad_sch]
2024-07-13 update case and main pcb
    [export_case v10_bottom-left.stl, export_case v10_bottom-right.stl, export_case v10_top-left.stl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]
2024-08-31 fix headset depth, increase side tolerance
    [export_case v21_bottom-left.stl, export_case v21_bottom-right.stl, export_case v21_top-left.stl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]
2024-10-22 move thumbs to inner side
    [export_case v23_bottom-left.stl, export_case v23_bottom-right.stl, export_case v23_top-left.stl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]
2024-10-31 stm32 mcu
    [mcu-stm32.kicad_pcb, mcu-stm32.kicad_sch]
2024-11-01 pcba version
    [bom.csv, designators.csv, pcb.kicad_pcb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]
2024-11-01 add 3d components
    [center.kicad_pcb, connector-left.kicad_pcb, connector-left.step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]
2024-11-01 replace ec11 with ec12
    [mcu.kicad_pcb, pcb.kicad_pcb]
2024-11-01 small updates
    [bom.csv, center.kicad_pcb, designators.csv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]
2024-11-02 add chocV2 case
    [chocV2_case v44_bottom-left.stl, chocV2_case v44_bottom-right.stl, chocV2_case v44_logo.stl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]
2024-11-04 chamfered case
    [chocV2_case v44_bottom-left.stl, chocV2_case v44_bottom-right.stl, chocV2_case v44_logo.stl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]
2024-11-10 rework stl export
    [chocV2_case v50_bottom-left.stl, chocV2_case v50_bottom-right.stl, chocV2_case v50_top-left.stl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]
2024-11-17 add stm32-per56
    [mcu-stm32-per56.kicad_pcb, mcu-stm32-per56.kicad_sch, mcu-stm32.kicad_pcb]
2024-11-17 add 3-part case
    [export-bottom_bottom-left-choc.stl, export-bottom_bottom-left-ks.stl, export-bottom_bottom-left-mx.stl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]
2024-11-20 improve case (mx version), rename files
    [bottom-center.stl, bottom-left-choc.stl, bottom-left-ks.stl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]
2024-11-26 add logo, move case files into subfolders
    [bottom-center.stl, bottom-left-choc.stl, bottom-left-ks.stl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]
2024-11-26 2-part case: increase tolerances, small improvements
    [bottom-left-choc.stl, bottom-left-ks.stl, bottom-left-mx.stl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]
2024-11-28 2-part case: shell bottom
    [bottom-left-choc.stl, bottom-left-ks.stl, bottom-left-mx.stl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]
2024-12-10 rework pcb for per56
    [bottom-center.stl, mcu-rp2040tiny-per56.kicad_pcb, mcu-rp2040tiny-per56.kicad_sch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]
2024-12-13 2part case: - bigger choc cutouts - smaller knob hole - thinner logo
    [bottom-left-choc.stl, bottom-left-ks.stl, bottom-left-mx.stl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]
2024-12-14 2part case: update logo
    [logo.stl]
2025-01-04 remove untested files
    [DES_r3_1.00u_x6.stl, DES_r3_dot_x2_r3_edge_x2.stl, bottom-center.stl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]
2025-01-04 restructure files
    [DES_r3_1.00u_x6.stl, DES_r3_dot_x2_r3_edge_x2.stl, bom.csv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]
2025-01-05 improve combined pcb
    [pcb.kicad_pcb]
2026-05-30 add molekula3
    [Choc_DES_minY-r2-edge-left.stl, Choc_DES_minY-r2.stl, Choc_DES_minY-r3-dot.stl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]
2026-06-02 readme and images for molekula3
    [knob.stl]
2026-07-21 add tws mcu and side36-choc
    [pcb-right-choc-spacing.step, side36-choc.kicad_pcb, side36-choc.kicad_sch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]
2026-07-22 add tws xiao mcu
    [tws-xiao-encoder.kicad_pcb, tws-xiao-encoder.kicad_sch, tws-xiao-encoder.step]
2026-07-24 final choc version
    [bom.csv, positions.csv, tws-xiao-encoder.kicad_pcb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]
2026-08-31 tws production files
    [bom.csv, pcb.kicad_pcb, positions.csv]
2026-09-22 tws stls
    [knob-lp.stl, knob.stl, plate-left.stl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]
2026-09-22 move files
    [knob-lp.stl, knob.stl, plate-left.stl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]
